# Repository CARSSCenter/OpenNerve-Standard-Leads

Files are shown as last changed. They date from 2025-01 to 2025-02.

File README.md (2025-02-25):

# OpenNerve-Standard-Leads
Leads for OpenNerve that can be manufactured under GMP using standard manufacturing processes

# About
This repository holds the design files, testing protocols, and benchtop testing results for a library of "standard" leads meant to interface with the OpenNerve IPG. Leads can be manufactured by Med-Ally LLC under GMP / design controls.

## VNS cuff electrode
This lead is designed to interface with the cervical vagus nerve or other peripheral nerves with diameters between 1 and 3.5 mm. It contains two radial platinum-iridium electrodes 1mm wide with 6mm spacing, embedded in a silicone cuff.


## SNS linear electrode
The linear electrode array is designed for sacral nerve stimulation or other peripheral stimulation. It contains four platinum-iridium electrodes 3mm wide, with a 3mm spacing, as well as anchor features for maintaining position in vivo.


## EMG needle electrode
The EMG lead contains a platinum-iridium needle electrode and suture needle. Two EMG electrodes can be attached using the interconnect for bipolar recording.

## ECG electrode
The ECG sensing lead contains two electrodes that are 3mm long, with 80mm spacing between them. It is based on the Boston Scientific 3400 S-ICD lead.

## AMS Motion Sensing Lead
The Accelerometer-based Motion Sensing (AMS) lead contains an [MIS2DH](https://www.st.com/en/mems-and-sensors/mis2dh.html) accelerometer encapsulated in silicone, which can communicate with the OpenNerve IPG via I2C.

# Disclaimer
The contents of this repository are subject to revision. No representation or warranty, express or implied, is provided in relation to the accuracy, correctness, completeness, or reliability of the information, opinions, or conclusions expressed in this repository.

The contents of this repository (the “Materials”) are experimental in nature and should be used with prudence and appropriate caution. Any use is voluntary and at your own risk.

The Materials are made available “as is” by USC (the University of Southern California and its trustees, directors, officers, employees, faculty, students, agents, affiliated organizations and their insurance carriers, if any), its collaborators Med-Ally LLC and Medipace Inc., and any other contributors to this repository (collectively, “Providers”). Providers expressly disclaim all warranties, express or implied, arising in connection with the Materials, or arising out of a course of performance, dealing, or trade usage, including, without limitation, any warranties of title, noninfringement, merchantability, or fitness for a particular purpose.

Any user of the Materials agrees to forever indemnify, defend, and hold harmless Providers from and against, and to waive any and all claims against Providers for any and all claims, suits, demands, liability, loss or damage whatsoever, including attorneys' fees, whether direct or consequential, on account of any loss, injury, death or damage to any person or (including without limitation all agents and employees of Providers and all property owned by, leased to or used by either Providers) or on account of any loss or damages to business or reputations or privacy of any persons, arising in whole or in part in any way from use of the Materials or in any way connected therewith or in any way related thereto.

The Materials, any related materials, and all intellectual property therein, are owned by Providers.

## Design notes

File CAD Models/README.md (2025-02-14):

All CAD files here were generated using SolidWorks.

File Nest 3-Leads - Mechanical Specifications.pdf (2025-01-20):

### Nest 3 – Leads

Mechanical Specifications

Page 1 of 9

### 1.0 Purpose

The purpose of this document is to provide product specifications for applicable Hornet Lead Package

### 2.0 Scope

In scope for this document are the product specifications inclusive to the Hornet IPG and charger; as part of the CARSS program Nest 3. The CARSS program stands for Center for Autonomic Nerve Recording and Stimulation Systems. The CARSS is part of the NIH Human Open Research Neural Engineering Technologies (HORNET) initiative for open-architecture, open-source implantable neuromodulation system. This includes a collaborative team between University of Southern California (USC, Los Angeles, CA), Medipace Inc (Pasedena, CA), and Med-Ally, LLC (Goose Creek, SC). The purpose of the system which the IPG and charger is a portion of is to enable community-supported neurotechnology platform to remove technical and financial hurdles to getting access to implantable neuromodulation technologies. Nest 3 focuses on a set of 5 standard leads: SNS, PDMS cuff, ECG, EMG, and AMS lead.

### 3.0 Definitions

Abbreviation | Definition
BLE | Bluetooth Low Energy. Operates on frequencies: 2.400 GHz – 2.4835 GHz
Controller | A computing device capable of running the NBS-EPG and IPG Controller application(s) tailored for physicians, the patient, or researchers.
IPG | Implantable Pulse Generator
HW | Hardware
SW | Software
PCB | Printed Circuit Board
PSD | Product Specifications Document
GUI | Graphical User Interface

Lead Mechanical Specifications
Page 2 of 9

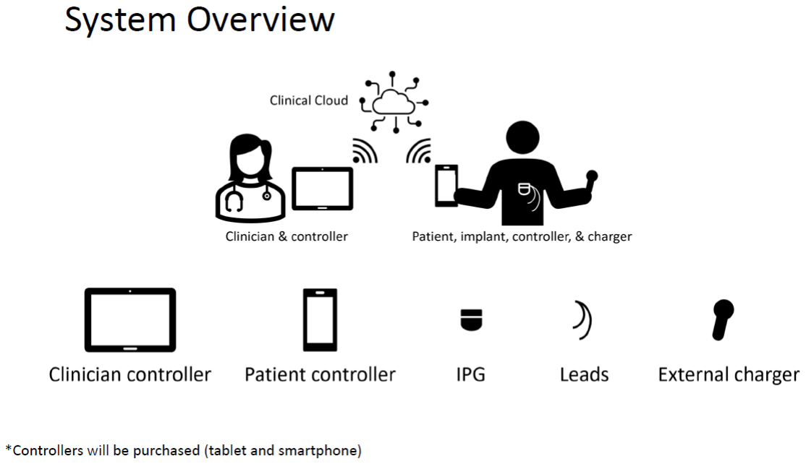
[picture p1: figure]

CONFIDENTIAL
All information contained in this document is confidential and is the sole property of Med-Ally Inc. Any reproduction in part or whole without the written permission of Med-Ally Inc. is prohibited.
Abbreviation | Definition
HIPAA | Health Insurance Portability and Accountability Act of 1996. U.S. legislation that provides data privacy and security for safeguarding medical information.
Wi-Fi | A facility allowing an electronic device to wirelessly transfer data or connect to the Internet using IEEE 802.11 standards. Operates on frequencies: 900 MHz, 2.4 GHz, 4.9 GHz, 5 GHz, 5.9 GHz and 60 GHz.
NIH | National Institute for Health
CARRS | Center for Autonomic Nerve Recording and Stimulation Systems
Hornet | Human Open Research Neural Engineering Technologies
Nest | Major component or module of the CARRS system

### 4.0 General Description of Product

The CARRS system is an open source system to enable developments in stimulation and sensing technologies. The system is capable of closed loop stimulation and sensing or can be used independently. The system components are: external charger and controller, implantable pulse generator, collection of interoperable and implantable leads.

Each portion of the CARSS system has been split into major components called nests. See

Page 3 of 9

figure below for details of major components or modules of the CARRS system:

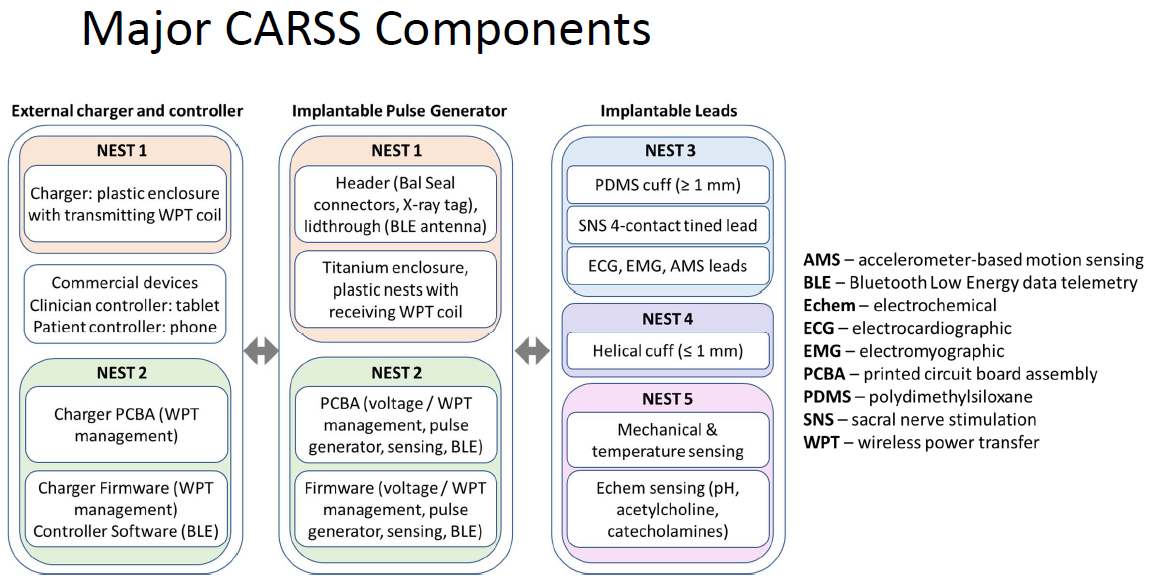
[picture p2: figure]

This document will only address Nest 1.
The IPG and charger for the CARRS system will be designed with the following engineering design principles as applicable:
- Material and component selection for maximizing the performance.
- Long-term reliability, redundancy, and fail-safe operations.
- Modularity, plug-and-play operation and off-the-shelf components.
- Preference for simpler and proven solutions over more complex and higher-risk ones.

### 6.0 Specifications

6.1 Leads Mechanical Specifications
PRD ID | Category | Specification Text
PRD-LDS-0001 | All | The leads are provided in the following lengths: 35 cm

Page 4 of 9

PRD ID | Category | Specification Text
| | 50 cm 50 cm 70 cm
PRD-LDS-0002 | All | The outside diameter of the leads shall be 1.27 mm diameter
PRD-LDS-0003 | All | The SNS, PDMS cuff, EMG, ECG, and AMS lead have 2 or 4 filar coiled leads with 0.70 mm pitch or greater.
PRD-LDS-0004 | All | The SNS, PDMS cuff, EMG, ECG, interconnect and AMS lead wire diameter is .102 mm/ 0.004” with 0.0127 mm/0.0005” thick coating.
PRD-LDS-0005 | All | The proximal contacts have 1.5mm length contacts.
PRD-LDS-0006 | All | The proximal set screw contact is 3mm in length.
PRD-LDS-0007 | All | Tines and trumpet anchor for anchoring can be added for each lead as needed.
PRD-LDS-0008 | All | The each connector utilizes a mechanism that holds the inserted lead in place. (e.g. set screw)
PRD-LDS-0009 | All | All the materials of the Lead Kit that are in contact with the body have been selected as known biocompatible.
PRD-LDS-0010 | All | The primary components for the Leads and interconnects shall be fabricated from the following materials: • Lead Body: Polyurethane, Pellethane 2363-55D • Proximal Inner Tube: PEEK • Distal Inner Tube: Polyurethane, Pellethane 2363-80A • Distal Electrodes: Platinum-Iridium (90/10) • Proximal Contacts: MP35N • Conductor Cable: PTFE coated Platinum-Iridium (80/20) • Setscrew: Titanium • Connector Block: MP35N

Page 5 of 9

PRD ID | Category | Specification Text
| | • Bal Seal connectors: MP35N and Pt-Ir • Silicone molded components Silicone Rubber -Med-4850, or similar • Connector block and set screw: 316L stainless steel • Misc Adhesives: Epoxy - Epotek 301, Silicone Rubber - Med-2000, urethane adhesive, silicone adhesive MED3-4213 • Suture: polypropylene or silk • Tines: pellethane • Suture Needle, crimp tubes: 316L Stainless Steel
PRD-SNS-0001 | SNS | SNS leads have electrodes on the distal end that are 3 mm in length with 3 mm space between electrodes
PRD-SNS-0002 | SNS | Up to 4 tines in series are added to the lead body to aid in lead retention and stability in vivo.
PRD-SNS-0003 | SNS | The lead systems incorporates a radio-opaque marker at the distal array in the form of platinum electrodes
PRD-SNS-0004 | SNS | The leads with a stylet inserted is able to pass completely through an 18-gauge needle
PRD-INT-0001 | Interconnect | The distal connector of the interconnect incorporates a connector block and set screw for securing the lead to the connector
PRD-INT-0002 | Interconnect | The distal connector of the interconnect accommodates two bipolar male connectors.
PRD-INT-0003 | Interconnect | The proximal connector of the interconnect interfaces with a quadipolar Sygnus Neuro Bal Seal connector in the IPG header.
PRD-INT-0004 | Interconnect | The interconnect connection portion is smaller than 0.5” X 1.5” X 0.5”
PRD-EMG-0001 | EMG | The EMG lead incorporates a Suture style needle

Page 6 of 9

PRD ID | Category | Specification Text
PRD-EMG-0002 | EMG | The EMG lead incorporates a suture connecting the needle to the stimulating portions of the lead
PRD-EMG-0003 | EMG | The EMG lead contains a single stimulating or sensing electrode
PRD-EMG-0004 | EMG | The EMG lead contains a Tumpet anchor to anchor electrode in place
PRD-EMG-0005 | EMG | The EMG lead interfaces with the bipolar connection.
PRD-EMG-0006 | EMG | The insertion needle length on the EMG lead is 32 mm
PRD-ECG-0001 | ECG | The ECG lead has two electrodes that can be 3mm to 100 mm apart.
PRD-ECG-0002 | ECG | The ECG lead has two anchor points: one at the end of the lead and the second proximal to the first electrode
PRD-ECG-0003 | ECG | The ECG lead interfaces with the bipolar connection
PRD-CUF-0001 | Cuff | The cuff electrode will have an inner diameter that accommodates nerves 2.5-5.5 mm in diameter – nominally 3.58 mm nerve.
PRD-CUF-0002 | Cuff | Cuff leads shall have two electrodes for bipolar stimulation.
PRD-CUF-0003 | Cuff | Cuff length along the nerve is 10 mm
PRD-CUF-0004 | Cuff | Lead exits cuff parallel to nerve
PRD-CUF-0005 | Cuff | Cuff electrode spacing is 2.5mm
PRD-CUF-0006 | Cuff | Electrodes are located 2.25mm inboard from edge of cuff
PRD-CUF-0007 | Cuff | Silicone cuff thickness is 1 mm
PRD-CUF-0008 | Cuff | Cuff includes dual sutures 35 mm long and 0.2mm diameter

Page 7 of 9

6.2 Testing Requirements
PRD ID | Specification Text
PRD-LDS-0011 | The leads contacts are electrically isolated to prevent interference between signals.
PRD-LDS-0012 | The Leads and Extensions shall be designed to withstand the following flexure cycles: -The Lead and Extension Connector shall withstand a minimum of 82,000 flex cycles. -The Lead and Extension body sections shall withstand a minimum of 47,000 flex cycles. Reference: EN45502-2-1 CENELEC Standard for Brady Pacemakers Testing will be performed per EN4552-2-1/ISO14708-2: 23.5.
PRD-LDS-0013 | Once the lead is locked in place into the IPG port or extension with the set screw fully torqued, the retention force of the lead shall be 10 N minimum along the lead axis relative to the connector. This retention force may exceed the destructive pull force of the inserted lead. EN45501-1 section 23.6 / ISO 14708-2: 23.6
PRD-LDS-0014 | When a tensile force of 5N is applied for 2 seconds along the main axis the of the lead or extension the assembly must not electrically and/or mechanically fail. ISO 14708-2: 23.3
PRD-LDS-0015 | Lead Insertion/Withdrawal Force Connector: The insertion and withdrawal force of a lead connector array into the IPG port connector or lead Extension port shall not exceed 2.2 lbs (9.8 N).
PRD ID | Category | Specification Text
PRD-AMS-0001 | AMS | The AMS lead is a quadripolar lead
PRD-AMS-0002 | AMS | The AMS lead has three suture points to anchor AMS distal end

Page 8 of 9

PRD ID | Specification Text
PRD-LDS-0016 | The interface between the extension distal connector body and a connected component shall not electrically and/or mechanically fail when tensile force of 2.2 lbf (9.8N) is applied between the components or across theirinterface. Deformation of componentsis allowable. Fracture of tubing orseparation of tubing from a component is not allowable. Examples of tensile force arrangements between an attached component and the Extension body.
PRD-LDS-0017 | The resistance for each connection in the distal connector shall remain ≤1000 Ohms and must not mechanically fail when bent 45°±2° off the main axis in any direction ISO 14708-2: 6.2.3
PRD-LDS-0018 | All the leads in the Leads Kit shall observe industry standard wiring practices for this type of application. The contact female connectors at the distal end and male contacts at the proximal end shall be connected through a one-to-one connection.
PRD-LDS-0019 | The proximal contact arrays of the Lead shall withstand 20 insertion and withdrawal cycles into the connector on the interconnect cable without causing physical or functional damage to the Lead.
PRD-LDS-0020 | The proximal contact arrays of the Lead and Extension shall withstand 20 insertion and withdrawal cycles into the port connector on the IPG without causing physical or functional damage to the Lead.
PRD-LDS-0021 | The lead assemblies should be able to withstand (function after experiencing) the following:

Page 9 of 9

PRD ID | Specification Text
| Accelerated aging per ISO 14708-1:19-1
PRD-LDS-0022 | When the lead or Extension assembly is dry in air, the electrical leakage between conductors at 100 ± 5 Volts DC shall be ≤10 microamperes. ISO 14708-2: 16.1
PRD-LDS-0023 | When the lead or Extension assembly is dry in air, the electrical leakage from any conductor to the outside lead body at 1000 ± 50 Volts DC shall be ≤0.75 microamperes per mm². ISO 14708-2: 16.2

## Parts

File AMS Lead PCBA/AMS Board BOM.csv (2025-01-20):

Name | Description | Designator | Manufacturer 1 | Manufacturer Part Number 1
ZRB15XR61A106ME01D | Capacitor, 10uf, X5R, 10V, 20%, 0402, Implant-grade | C200 | Murata | ZRB15XR61A106ME01D
GCM155R71C104KA55 | Capacitor, 0.1uF, X7R, 16V, 10%, 0402, Implant-grade | C201 | Murata | GCM155R71C104KA55J
MIS2DHTR | Analog Circuit, Accelerometer, LGA-12 | U200 | STMicroelectronics | MIS2DHTR

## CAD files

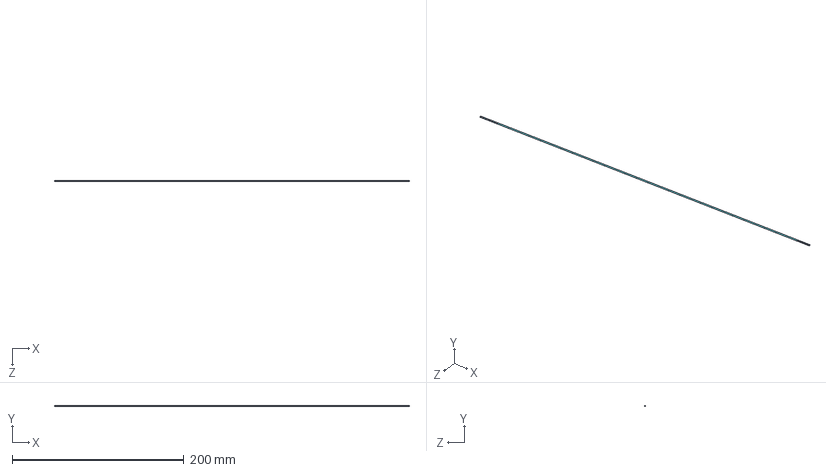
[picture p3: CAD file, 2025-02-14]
CAD Models/8247, 4 X 4 Lead Assembly with Tines, Rev. 2.1.STEP
413.5 x 1.27 x 1.27 mm
8177 Contact, Proximal,1.50 MM. Rev 1.0 x 4
8181 Pellethane 55D Tube, 1.245 MM, Rev. 1.0 x 4
8184, Proximal Lead Tip, Rev. 1.0
8263 Peak Single Lumen Tube Rev 2.0
8146 Proximal Contact - 3 mm Rev 1.0
8145 Electrode - 3 mm Rev 1.0 x 4
8179, Pellethane Tube 55D. 3.00MM, Rev. 1.0 x 3
8147 Distal Tip Rev 2.0
8204, Pellethane Tube 55D, 374 mm, Rev. 1.0
8178, Pellethane Tube 55D, 0.87MM, Rev. 1.0

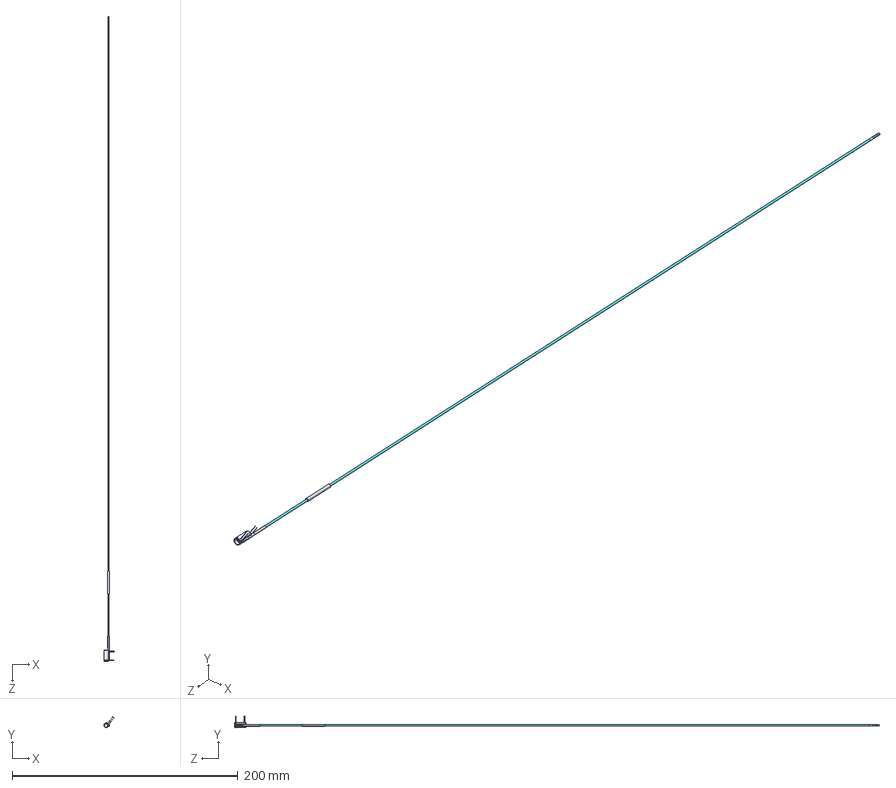
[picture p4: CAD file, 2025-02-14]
CAD Models/8289, Bipolar Cuff, Rev 1.1.STEP
9.17 x 10.2 x 571.5 mm
3mm I.D. Cuff
3mm Electrode x 2
3mm Suture Cord no furl x 2
3mm I.D. Cuff transition
8158 Proximal Contact-3 mm Rev 2.0
8184, Proximal Lead Tip, Rev. 1.1
Inner Connect XXXX, Outer Tubing 80A 550 mm, Rev 1.0
XXXX, Outer Tubing 80A, 1.245mm, Rev 1.0 x 2
8159 Proximal Contact-1.5 mm Rev 2.0 x 2
8263, PEEK Single Lumen Tube, Rev 1.1
8XXX, Silicone Tube, Rev 0.1

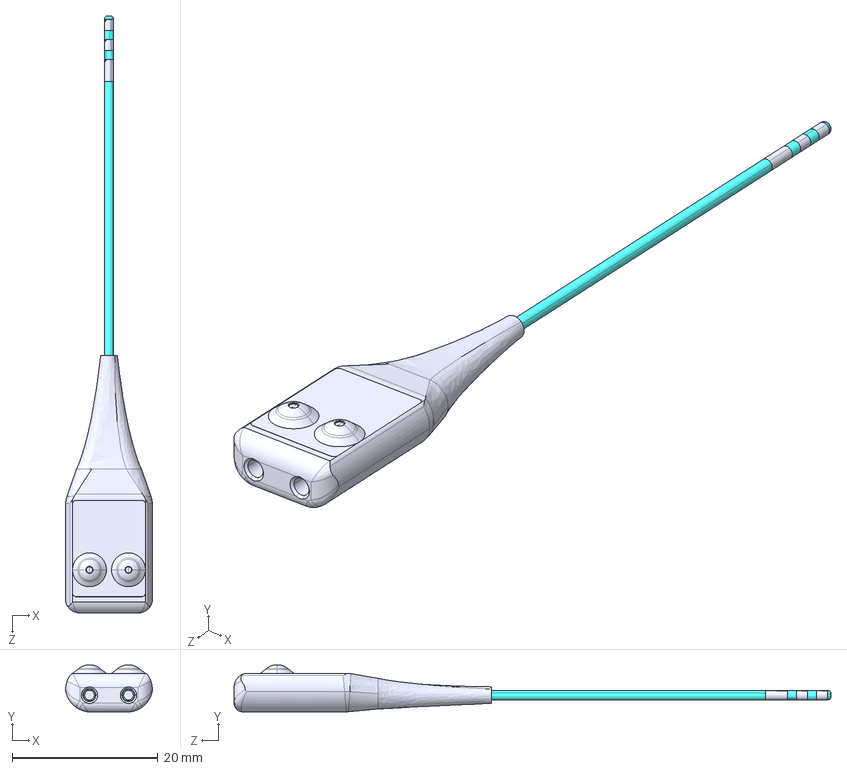
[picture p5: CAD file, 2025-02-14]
CAD Models/8340, Lead Extension, Rev 1.2.STEP
11.9 x 6.43 x 81.9 mm
septum top cover
8XXX, 2X2 Interconnect - Main, Rev 0.3
MAN_ExtenderConnectorBlock x 2
MAN_BalCon_27Mar2019 x 2
MAN_BalSeal x 6
8158 Proximal Contact-3 mm Rev 1.0
8184, Proximal Lead Tip, Rev. 1.0
Inner Connect XXXX, Outer Tubing 80A 60 mm, Rev 1.0
XXXX, Outer Tubing 80A, 1.245mm, Rev 1.0 x 2
8159 Proximal Contact-1.5 mm Rev 1.0 x 2
NK SCR 001 #2-56 X .062 LONG CUP POINT SETSCREW REV. 3.0_NT10015-000_A x 2
8263 Peak Single Lumen Tube Rev 1.0

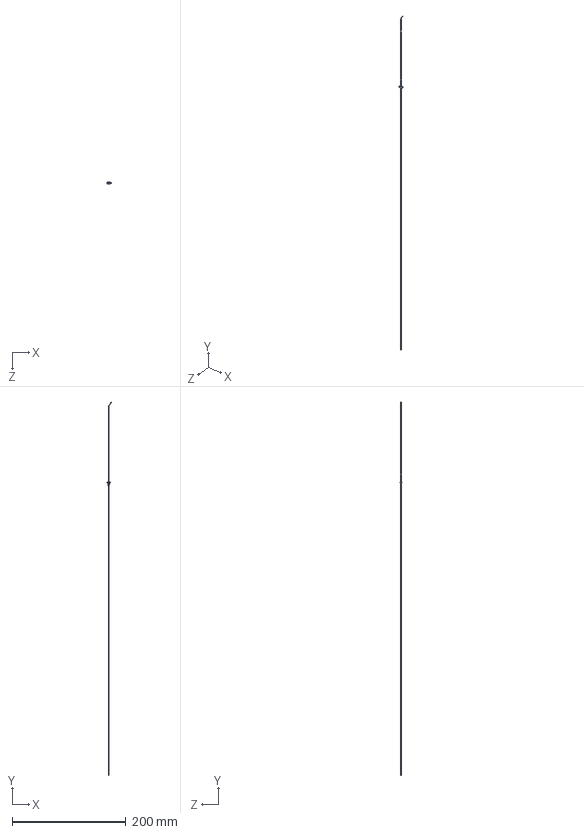
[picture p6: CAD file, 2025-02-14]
CAD Models/8291, EMG Lead, Rev 1.1.STEP
7.88 x 655.0 x 4.00 mm
8307, 1 Filar Coil, Rev 0.1 x 2
ECG XXXX, Outer Tubing 80A 60 mm, Rev 1.1
8292, EMG Suture-Needle, Rev 1.0
8294, Polypropylene Filament, Rev 1.0
8263, PEEK Single Lumen Tube, Rev 1.1
8158 Proximal Contact-3 mm Rev 1.0
8177 Contact, Proximal,1.50 MM. Rev 1.0
8XXX Electrode - 15 mm Rev 0.1
8309, Trumpet Anchor, Rev 1.0
8XXX, Distal Lead Tip, Rev. 0.1
8184, Proximal Lead Tip, Rev. 1.1
8181 Pellethane 55D Tube, 1.245 MM, Rev. 1.0

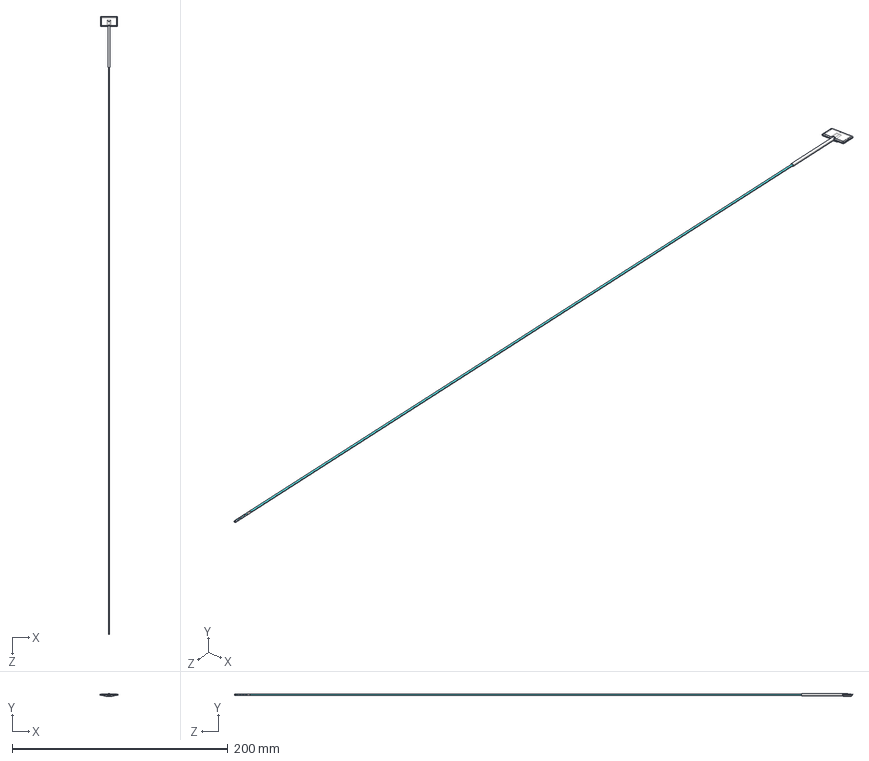
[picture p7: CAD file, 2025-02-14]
CAD Models/8303, AMS Lead, Rev 1.1.STEP
16.0 x 3.12 x 572.5 mm
8XXX, 4 80Pt20Ir Wire
Inner Connect XXXX, Outer Tubing 80A 550 mm, Rev 1.0
8263, PEEK Single Lumen Tube, Rev 2.1
8262, Silicone Tubing 1.25 mm ID x 1.5 in, Rev 0.1
8159 Proximal Contact-1.5 mm Rev 1.0 x 4
8158 Proximal Contact-3 mm Rev 1.0
pinShape x 16
8XXX, Silicone Dip, Rev 0.1
8181 Pellethane 55D Tube, 1.245 MM, Rev. 1.0 x 4
8184, Proximal Lead Tip, Rev. 1.1

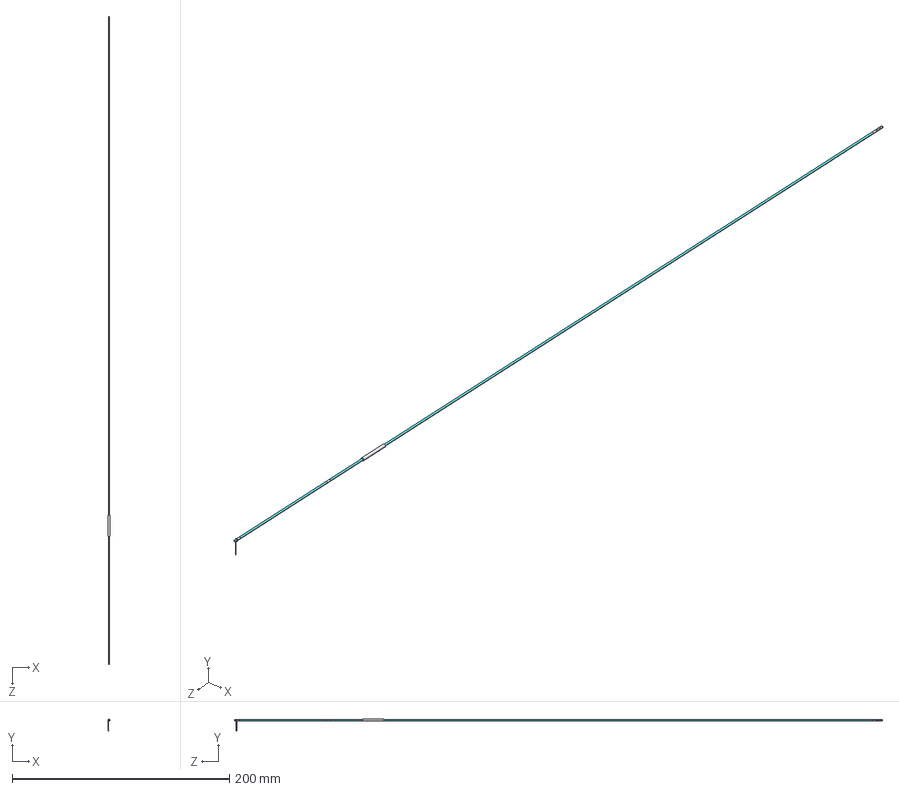
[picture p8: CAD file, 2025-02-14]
CAD Models/8290, ECG Lead, Rev. 1.1.STEP
2.00 x 11.0 x 596.7 mm
ECG XXXX, Outer Tubing 80A 60 mm, Rev 1.0
8262, Silicone Tubing 1.25 mm ID x 2 cm, Rev 0.1
8158 Proximal Contact-3 mm Rev 1.0
8389, Electrode, Rev 1.1 x 2
8159 Proximal Contact-1.5 mm Rev 1.0 x 2
8XXX, 1.27mm Suture Cord no furl, Rev 0.1
8263, PEEK Single Lumen Tube, Rev 1.1
8XXX, Distal Lead Tip, Rev. 0.1
8181 Pellethane 55D Tube, 1.245 MM, Rev. 1.0 x 2
ECG XXXX, Outer Tubing 80A 8 mm, Rev 1.0
XXXX, Outer Tubing 80A, 1.245mm, Rev 1.0
8184, Proximal Lead Tip, Rev. 1.1

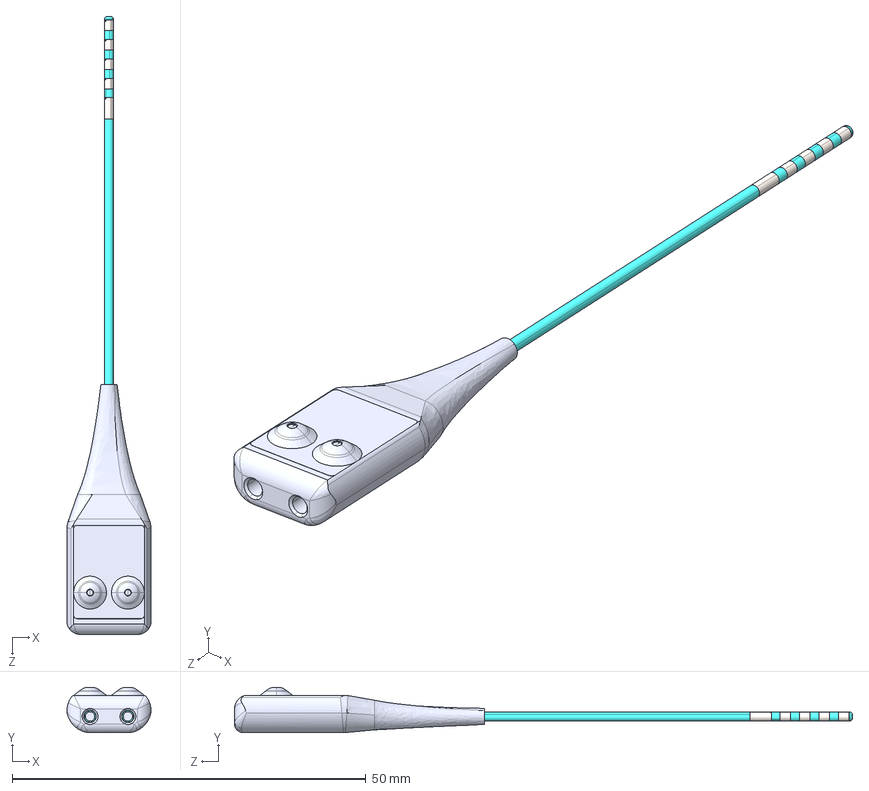
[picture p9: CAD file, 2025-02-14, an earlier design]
CAD Models/8340, Lead Extension, Rev 1.1.STEP
11.9 x 6.43 x 87.4 mm
septum top cover
8XXX, 2X2 Interconnect - Main, Rev 0.3
MAN_ExtenderConnectorBlock x 2
MAN_BalCon_27Mar2019 x 4
MAN_BalSeal x 8
8158 Proximal Contact-3 mm Rev 1.0
8184, Proximal Lead Tip, Rev. 1.0
Inner Connect XXXX, Outer Tubing 80A 60 mm, Rev 1.0
XXXX, Outer Tubing 80A, 1.245mm, Rev 1.0 x 4
8159 Proximal Contact-1.5 mm Rev 1.0 x 4
NK SCR 001 #2-56 X .062 LONG CUP POINT SETSCREW REV. 3.0_NT10015-000_A x 2
8263 Peak Single Lumen Tube Rev 1.0

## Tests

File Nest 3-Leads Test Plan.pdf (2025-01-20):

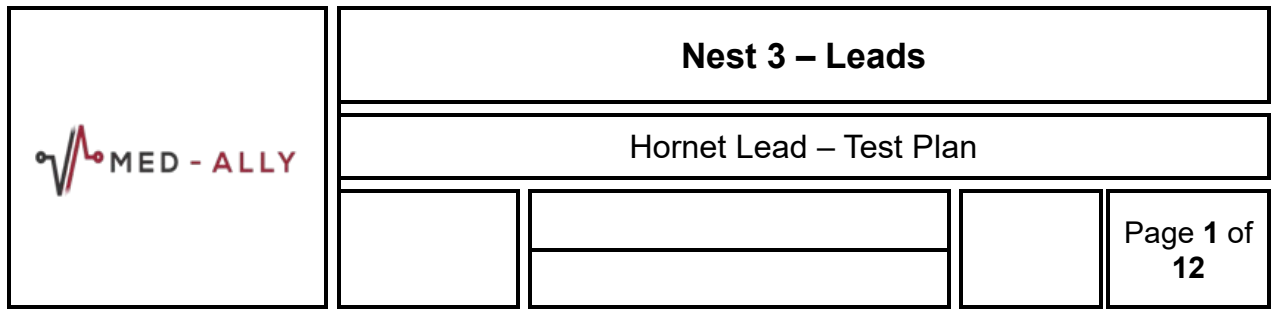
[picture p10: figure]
Nest 3 – Leads; Hornet Lead – Test Plan; Page 1 of 12

### 1. Purpose

The purpose of this document is to summarize how The Hornet Leads will be tested to show that the design, construction and functionality of the device meets design and functionality requirements and complies with applicable standards.

### 2. Scope

This document is valid for the Hornet Leads. The test plan outlined in this document is progressive and may be released at various stages prior to finalization. This document includes an overview of applicable testing requirements, equipment, and documentation.

### 3. References

Document No. | Title
ISO 14708-1 & 3 | Implants for surgery – Active Implantable Medical Devices
| ISO 11607-1:2006 and ASTM F1980-07(2011)
BS EN 45502-2-1:2003 | Active Implantable Medical Devices Part 2-1: Particular requirements for active im-plantable medical devices intended to treat bradyarrhythmia (cardiac pacemakers)

### 4. Definitions

Abbreviation or Term | Definition
DVT | Design Verification Test
Engineering Bench Level Test | Also known as Engineering Design Verification. Prototype samples are created and subjected to internal and external testing to verify that design requirements and specifications are being met. The results from these tests will determine if the product gets released to Production.
IPG | Implantable Pulse Generator

### 5. General Description of Product

The CARRS system is an open source system to enable developments in stimulation and sensing technologies. The system is capable of closed loop stimulation and sensing or can be used independently. The system components are: external charger and controller, implantable pulse generator, collection of interoperable and implantable leads. This document is focused on leads only.

### Hornet Lead – Test Plan

### Page 2 of 12

CONFIDENTIAL
All information contained in this document is confidential and is the sole property of Med-Ally Inc. Any reproduction in part or whole without the written permission of Med-Ally Inc. is prohibited

### 6. Methods

Each test will be summarized via an approved quality management system controlled protocol. The test will be conducted per the protocol with records and deviations recorded. Results and conclusions along with any needed discussion and recommendations will be documented in a report. The test results will be compiled and summarized in a Test Report or appendix.

### 7. Sample Size Strategy

Three to nine samples for each test will be used. This number is to show the ability of the lead to meet the shown criteria. For formal DVT testing for human use these values will need to be reviewed per use case based on risk and application to evaluate if test and sample size can be utilized or if the test needs to be supplemented or repeated. Planned testing units are represented below for each test.

### 8. DVT Test Details 8.1. Tests that require pre-conditioning

8.1.1. Baseline functional lead measurements shall be recorded and cataloged.
8.1.2. Ensure measurements for each lead it clearly identifiable.
8.1.3. Preconditioning protocol:
8.1.3.1 Pre-conditioning bath of 9 g/l saline at 37 deg C +/- 5 deg C submerged for 10 days. 8.1.3.2 Immediately prior to testing the lead shall be rinsed in distilled or deionized water, and then wiped free of surface water.
Test | Testing Details
Lead Body Pull Test at 5 N | Purpose | ►Leads shall withstand the tensile forces that might occur after implantation, without fracture of any conductors or joints or breaching of any functional electrical isolation.
| Standards | ►ISO 14708-2:23.3
| Acceptance Criteria | ► Leads exhibits no permanent elongation in exceeds of 5% nor any permanent functional damage; ►The continuity measurements do not change from baseline to after conditioning; ►The leakage current measured between each conductor and the reference electrode and between any two conductors that have an exposed conductive surface intended for contact with tissue is <= 2 mA during the voltage application.
| Equipment | ►preconditioning bath of approximately 9 g/l saline at 37 deg C +/- 5 °C, ►a tensile load tester,

### Hornet Lead – Test Plan

### Page 3 of 12

CONFIDENTIAL
All information contained in this document is confidential and is the sole property of Med-Ally Inc. Any reproduction in part or whole without the
Test | Testing Details
| | ►a resistance meter, ►a reference electrode plate having a noble metal surface with a minimum area of 500 mm2 that can be located in the test bath (same as precondition-ing bath requirements) ►a leakage current tester, capable of applying 100 V and supplying a current of at least 2 mA.
| Lead Samples | ►20 cm SNS leads will be utilized. ►SNS lead was chosen because the quadripolar leads represent the worst case of lead body stresses with 4 filar vs. 2 filar. ►Qty 9 as representative samples will be used.

Test Set Up

►After conditioning:
►The LEAD shall be fitted in the tensile tester, clamped at the metallic surface of the LEAD connector pin and at the appropriate point on the distal end of the LEAD. The distance between the lamping points shall be measured.
- The lead shall be subjected to a tensile load, limited to a value causing 20% elongation, otherwise increased to at least 5N. The tensile load shall be sustained for at least 1 min, then relieved.
►The tensile load application shall be repeated for each combination of distal end tip and lead connector pin. This may be accomplished by using multiple leads as the test sample.
►The electrical continuity of each conduction path shall be verified by measuring DC resistance
►The insulation integrity of each lead shall be verified by immersing the outer covering, other than 20 mm of any exposed conductive surface, in the test bath. The test specimen(s) shall be placed in the test bath within 30 min of removal from the preconditioning bath and shall be immersed in the test bath for a minimum of 1 h before proceeding. The test specimen shall be positioned in the test bath so that the lead body is not less than 50 mm nor more than 200 mm from the reference electrode plate.
►The insulation shall then be subjected to a 100 V +/- V DC test potential between each conductor and the reference electrode and between any two conductors that have an exposed conductive surface intended for contact with tissue. The test voltage shall attain the full value within 0,1 s to 5 s. The test potential shall be maintained at full value for at least 15 s before being lowered to zero.
Report ► Generate Report

### Hornet Lead – Test Plan

### Page 4 of 12

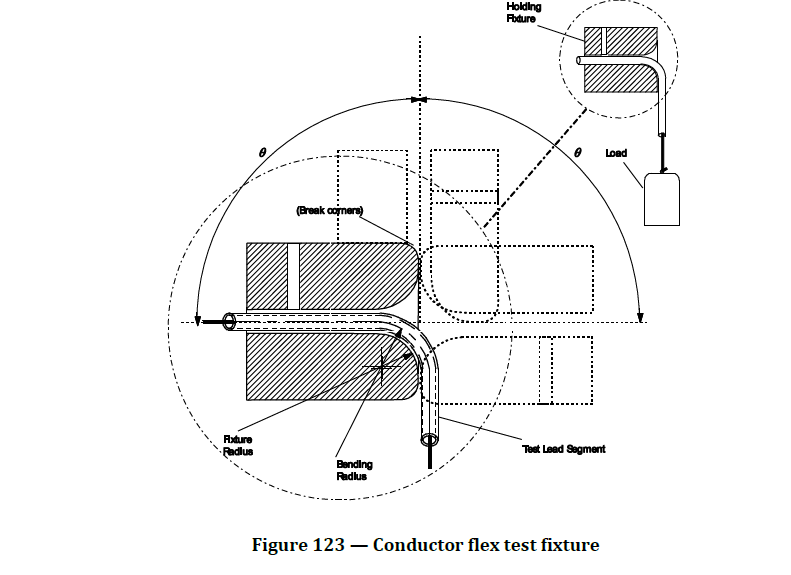
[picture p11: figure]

CONFIDENTIAL
All information contained in this document is confidential and is the sole property of Med-Ally Inc. Any reproduction in part or whole without the
Test | Testing Details
| Purpose | ►Implantable leads shall withstand the flexural stresses that might occur after implantation, without fracture of any conductor. ►Test 1 to be conducted to be conducted 5 cm from the connecting features of stimulation or sensing on the distal end on lead body. ►Test 2 to be conducted on each type of uniform lead body on the proximal end construction for each lead type.
| Standards | ►ISO14708-2:23.5
| Acceptance Criteria | ► Measured resistance and conductance has not significantly varied from baseline values.

Lead Flexure
Cycling Test

Equipment

►a resistance meter,
►functional test equipment ►Figure 123 Test fixture:

►Figure 124 Test Fixtures

### Hornet Lead – Test Plan

### Page 5 of 12

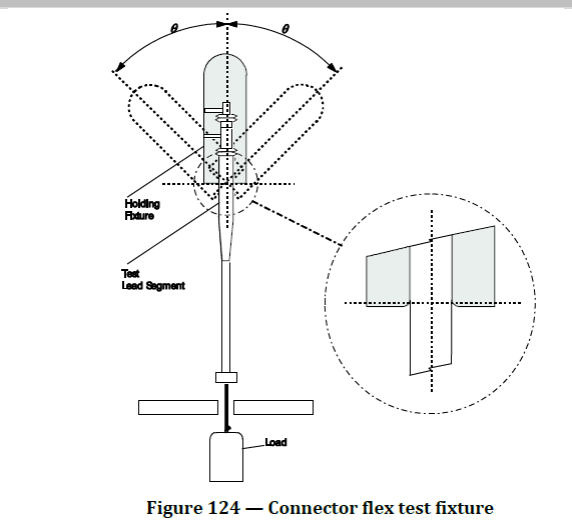
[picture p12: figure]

CONFIDENTIAL
All information contained in this document is confidential and is the sole property of Med-Ally Inc. Any reproduction in part or whole without the
Test | Testing Details

Lead Samples

►20 cm leads will be utilized.
►Qty 3 SNS leads as representative samples will be used of a quadripolar lead body and Qty 3 Cuff/VNS lead samples will be used of a bipolar lead body sample.
►A mix of SNS (4 filar) and VNS leads (2 filar) will be utilized to compare representative samples for both lead configurations. The test plan can be used across different lead applications due to the test purpose as outlined above.

Test Set Up

►Perform preconditioning
Test 1: Flexible lead segments – 5 cm from distal end
►Using special holding fixture (see figure 123 from standard). The inside bore of the fixture shall be no greater than 110% of the diameter of the lead segment under test. At the lower end of the fixture, the inside surface shall be formed into a bell mouth having a radius such that, when the test segment conforms to the contour of the fixture, the center line of the test segment forms a 6 mm +/- 0.1 mm center line bending radius
►The fixture shall be mounted in a machine that can oscillate the fixture 90 +0/-5 degrees from the vertical and forces the test segment to flex in the bell mouth of the fixture. The lead test segment shall be mounted to hang vertically under gravity in the holding fixture, oriented in the worst-case test condition when the test segment allows multiple orientations. A load sufficient to ensure that the center line of the test segment conforms to the bending radius shall be attached to the lower end of a thin, flexible line (cord) strung through the test segment. For LEAD bodies with no accessible

### Hornet Lead – Test Plan

### Page 6 of 12

CONFIDENTIAL
All information contained in this document is confidential and is the sole property of Med-Ally Inc. Any reproduction in part or whole without the
Test | Testing Details lumen, a minimal tensile load may be applied directly to the test segment, so that it conforms to the bending radius. ►The fixture shall be oscillated through an angle 90 degrees +0/-5 deg each side of vertical at a rate of approximately 2 Hz for a minimum of 47,000 cycles. (minimize vibration). ►The test shall be repeated for each unique uniform flexible part of the lead body. ►Post flexure measure resistance and functional conductivity Test 2: Lead proximal connector joints between lead and connector body – proximal end ► Using special holding fixture (see figure 124 from standard) (similar in form to header). The holding fixture shall be made of rigid materials with representative corners and materials to header. ►The holding fixture shall be mounted in a machine that can rotate the fixture 45 deg +/- 2 deg from the vertical (figure 124 from standard). The center of rotation shall be in the plane where the rounded corners of the holding fixture begin. The holding fixture shall allow the lead connector an attached lead segment to hang vertically under gravity. The lead connector shall be fitted into the holding fixture, oriented in the worst-case test condition and retained by the set screw mechanism. ►A load shall be attached to the lead segment 10 cm +/- 0.5 cm from the center of rotation of the holding fixture. The load attachment mechanism shall ensure that there is no relative motion between the conductor and the tubing at the point of attachment. The load shall be 100 g +/- 5 g (including the attachment mechanism). ►The holding fixture shall then be oscillated 45 deg +/- 2 degrees each side of vertical at a rate of approximately 2 Hz for a minimum of 82,000 cycles. ►The test shall be repeated for each joint in the lead body. ►Post flexure measure resistance and functional conductivity
Report | ►Generate Report
Qualification Test | Testing Details
Lead Connector | Purpose | ► Demonstrate the retention force provided by the implantable connector shall be greater than or equal to 10 N. For the lead to header and lead to

### Hornet Lead – Test Plan

### Page 7 of 12

CONFIDENTIAL
All information contained in this document is confidential and is the sole property of Med-Ally Inc. Any reproduction in part or whole without the
Qualification Test | Testing Details
Pull Test at 10 N | interconnect.
Standards | ►ISO 14708-2: 23.6
Acceptance Criteria | ►The lead shall not be disconnected at value of 10 N or less.
Equipment | ► The insertion and removal force will be measured by the Instron S/N 3367Q1264. ► Saline bath, approximately 9 g/l at 37oC ± 5oC
Lead Samples | ►20 cm leads will be utilized. ►Qty 3 SNS leads as representative samples will be used of a quadripolar lead body and Qty 3 Cuff/VNS lead samples will be used of a bipolar lead body sample. ►A mix of SNS (4 filar) and VNS leads (2 filar) will be utilized to compare representative samples for both lead configurations. The test plan can be used across different lead applications due to the test purpose as outlined above.
Test Set Up | ► The implantable connector pair shall be mated and immersed in a saline bath, approximately 9 g/l at 37oC ± 5oC, for a minimum of 10 days. ► Remove the lead from the saline bath. ► Subject the lead to header to straight pull of 10 N +/- 0.5 N for a minimum of 10 seconds.
Report | ►Generate report

### 8.2. Tests that DO NOT require pre-conditioning

8.2.1. Baseline functional lead measurements shall be recorded and cataloged.
8.2.2. Ensure measurements for each lead it clearly identifiable.
Qualification Test | Testing Details
Lead leakage current < 10 uA | Purpose | ► To test that the lead has effective functional electrical insulation between conductors.
| Standards | ►ISO 14708-2: 16.1 / IEC 60601-1, IEC 62353
| Acceptance Criteria | ►The leads must have no more than 100 uA current leakage when tested to a minimum of 50 V DC in normal condition (NC). ► Type BF – Electrically connected to Patient but not directly to heart

### Hornet Lead – Test Plan

### Page 8 of 12

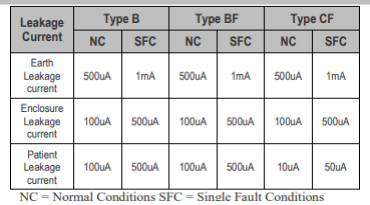
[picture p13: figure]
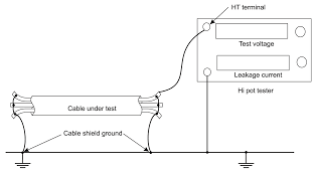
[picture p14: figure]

CONFIDENTIAL
All information contained in this document is confidential and is the sole property of Med-Ally Inc. Any reproduction in part or whole without the
Qualification Test | Testing Details
Equipment | ► Guardian Electrical Safety Analyzer model 19032 from Chroma System Solutions to measure current leakage.
Lead Samples | ►20 cm leads will be utilized. ►Qty 9 SNS leads as representative samples will be used of a quadripolar lead body as the worst case sample.
Test Set Up | ► High and low leakage current limits will be set to 1 mA. The applied voltage will be set to 50 V DC.
Report | ►Generate Report
Qualification Test | Testing Details
Lead DC Charge <= 0.75 UA/mm² | Purpose | ►To confirm the maximum current density at any electrode is no more than 0.75 uA/mm² . Except for its intended function, an IMPLANTABLE PULSE GENERATOR, when in use, shall be electrically neutral. No d.c. leakage current of more than 1 μA shall occur in any of the current pathways of the CASE TERMINALS and no more than 0.1 μA in the current pathways of any other TERMINAL.
| Standards | ►ISO 14708-2: 16.2

### Hornet Lead – Test Plan

### Page 9 of 12

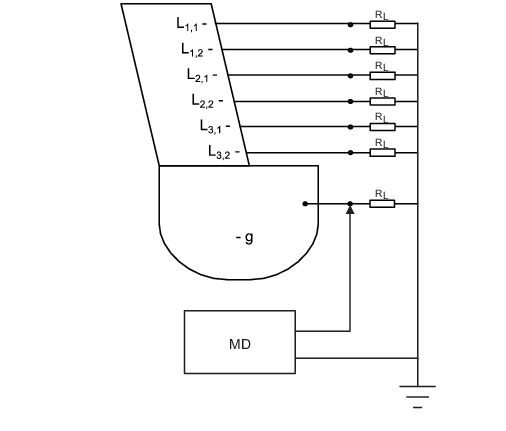
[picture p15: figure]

CONFIDENTIAL
All information contained in this document is confidential and is the sole property of Med-Ally Inc. Any reproduction in part or whole without the
Qualification Test | Testing Details
| Acceptance Criteria | ► maximum current density at any electrode is no more than 0.75 uA/mm² except for its intended function.
| Equipment | ► Guardian Electrical Safety Analyzer model 19032 from Chroma System Solutions to measure current leakage.
| Lead Samples | ►40 cm leads will be utilized. ►Qty 9 VNS leads as representative samples will be used of a cuff lead sam-ple as this is the most likely to use high frequency signals, which represents the highest risk for lead DC charge.

Test Set Up

- The IMPLANTABLE PULSE GENERATOR shall be set to the nominal settings recommended by the MANUFACTURER (i.e. the “factory recommended settings”) but with the PULSE AMPLITUDE and PULSE DURATION programmed to the highest available settings.
►Each electrically conductive part of the IMPLANTABLE PULSE GENERATOR in contact with body tissue when the device is implanted shall be identified and connected to a common bus through 500 1 % load resistors RL (see Figure 122). For devices with fewer terminals than shown in Figure 122, the associated resistors RL are not used.

Example image:

►Measure the average direct voltage across each load resistor with the measuring device. Steady-state conditions shall be reached before the measurement is made.
►The measurement of the individual terminal currents may be made with a plurality of measuring devices.

### Hornet Lead – Test Plan

### Page 10 of 12

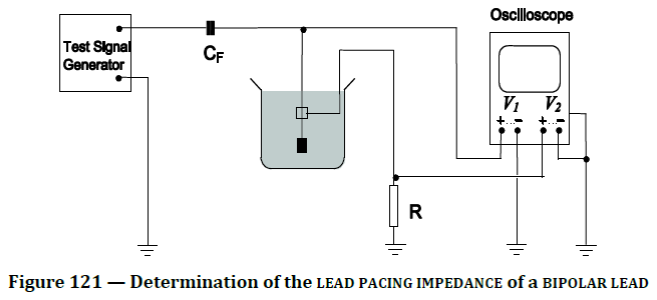
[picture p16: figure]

CONFIDENTIAL
All information contained in this document is confidential and is the sole property of Med-Ally Inc. Any reproduction in part or whole without the
Qualification Test | Testing Details
| Report | ►Generate report
Qualification Test | Testing Details
| Purpose | ►Measurement of lead stimulating impedance using in vitro approach
| Standards | ► ISO 14708-2: 6.2.3
| Acceptance Criteria | ►Resistance is acceptable. Typically < 50 ohms.
| Equipment | ►Oscilloscope ►Test Signal Generator
| Lead Samples | ►40 cm leads will be utilized. ►Qty 9 VNS leads as representative samples will be used of a cuff lead sample with the DC charge test.

Lead contact
impedance < 1000
ohm

Test Set Up

- The LEAD shall be inserted into the test body so that the ELECTRODES are at least 10 mm from any fluid boundary.
►The test signal generator shall be connected through a 33 μF +/- 5 % series film capacitor (CF) to the LEAD, the metal plates and the oscilloscope as shown in Figure 121.

►Set the signal generator to provide negative pulses, 65 +/- 5 per minute, amplitude 4 V+/-0.1 V and duration (Tp ) of 0.5 ms +/- 0.05 ms. The LEAD current shall be determined by measuring the voltage drop across the 10

### Hornet Lead – Test Plan

### Page 11 of 12

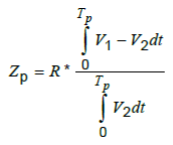
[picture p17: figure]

CONFIDENTIAL
All information contained in this document is confidential and is the sole property of Med-Ally Inc. Any reproduction in part or whole without the
Qualification Test | Testing Details
| | ohm +/- 2 % resistor. ►The LEAD stimulation IMPEDANCE (Zp) shall be calculated, using the mean values of voltage and current, by applying the formula: NOTE See Figure 120 and Figure 121 for definitions of V1 and V2.
| Report | ► Generate Report
Qualification Test | Testing Details
| Purpose | ►Ensure Leads meet requirements, standards, and performance characteristics for the 2 years.
| Standards | ►ISO 14708-1:19-1
| Acceptance Criteria | ►Meets functional specifications at appropriate time points. ►There is no visible corrosion or delamination apparent that would lead to connection of two conducting surfaces. ►No unacceptable risks become evident as the device ages.
| Equipment | ►Oven ►RH Meter ►Timer ►Temperature Probe and Meter
| Lead Samples | ►20 cm leads will be utilized. ►Qty 9 VNS leads as representative samples will be used of a cuff lead sample with the DC charge test.
| Test Set Up | ►Consider the composition, morphology, thermal transitions, additives or other chemical properties present in materials. ► Assumptions: - Conditioned in 0.9% sodium chlorine bath heated to 55 degrees C per accelerated aging standards outlined in ISO 11607-1:2006 and ASTM F1980-07(2011)

Lead accelerated
aging test

### Hornet Lead – Test Plan

### Page 12 of 12

CONFIDENTIAL
All information contained in this document is confidential and is the sole property of Med-Ally Inc. Any reproduction in part or whole without the
Qualification Test | Testing Details
- Accelerating Aging Temperature 55 degrees C
- Nominal temperature 37 degrees C
- Q10 value of 2.0
- With the above calculations the testing timepoints:
| • 3 months = 26 days • 12 months = 52 days • 24 months = 105 days • 36 months = 314 days • 48 months = 419 days • 60 months = 524 days
- Team may decide to increase temperature depending on timepoint
| calculation will change accordingly ►Place the Aging Parts in prepared saline bath and place in designated oven and record start time and date. Record temperature measurement calibration information. ►Age Samples at Accelerated Aging Temperature, and in parallel, age samples at room temperature. ►At the end of each Aging Test Time Interval, visually inspect device and verify performance requirements of the device. Place device back in chamber after testing to continue the conditioning.

Report

| ►Generate Report, including aging conditions (test temperature, humidity, cycle, ambient temperature, time frame, sample sizes, time intervals of sampling, and specific tests at each time interval). Record all instruments used and calibration information. Document test standard references and

methods of evaluation.

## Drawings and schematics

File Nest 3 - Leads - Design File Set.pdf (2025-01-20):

# DRAFT

ITEM NO. | PART NUMBER | DESCRIPTION | QTY. | | REVISIONS

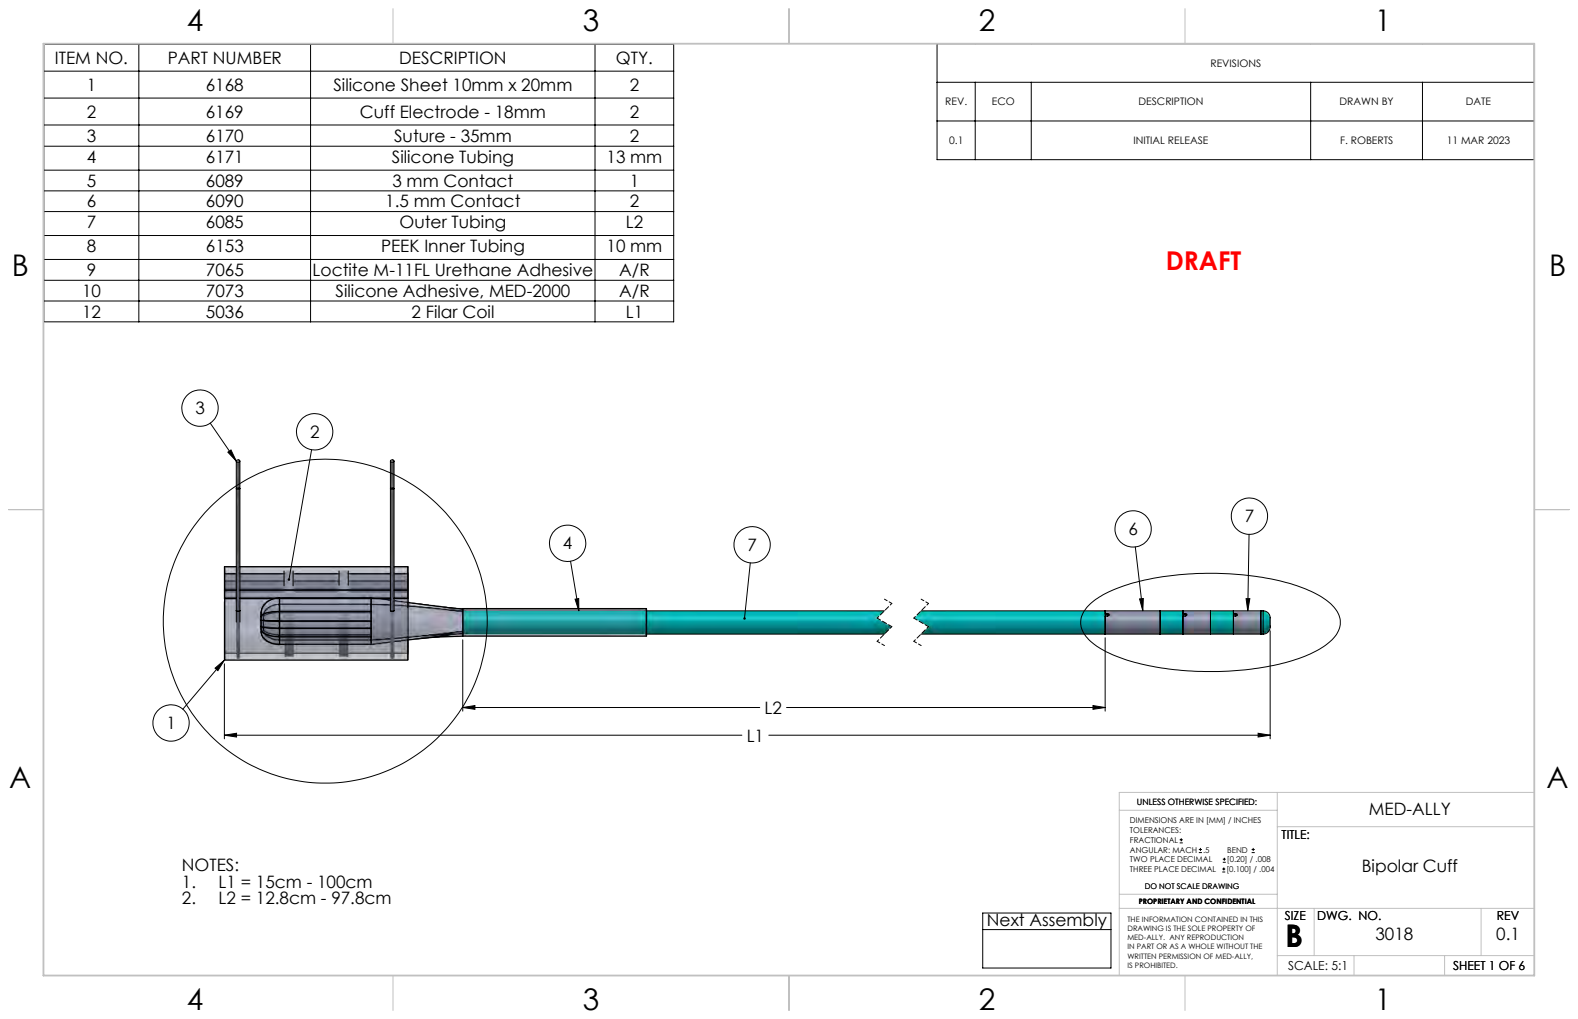
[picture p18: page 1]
NOTES: 1. L1 = 15cm - 100cm 2. L2 = 12.8cm - 97.8cm; TITLE:; ANGULAR: MACH .5; BEND; TWO PLACE DECIMAL; MED-ALLY; Next Assembly; Bipolar Cuff

1 | 6168 | Silicone Sheet 10mm x 20mm | 2
2 | 6169 | Cuff Electrode - 18mm | 2
3 | 6170 | Suture - 35mm | 2
4 | 6171 | Silicone Tubing | 13 mm
5 | 6089 | 3 mm Contact | 1
6 | 6090 | 1.5 mm Contact | 2
7 | 6085 | Outer Tubing | L2
8 | 6153 | PEEK Inner Tubing | 10 mm
9 | 7065 | Loctite M-11FL Urethane Adhesive | A/R
10 | 7073 | Silicone Adhesive, MED-2000 | A/R
12 | 5036 | 2 Filar Coil | L1

REV. | ECO | DESCRIPTION | DRAWN BY | DATE

0.1 | | INITIAL RELEASE | F. ROBERTS | 11 MAR 2023

UNLESS OTHERWISE SPECIFIED:
DIMENSIONS ARE IN [MM] / INCHES
TOLERANCES:
FRACTIONAL
THREE PLACE DECIMAL [0.100] / .004
DO NOT SCALE DRAWING
PROPRIETARY AND CONFIDENTIAL

THE INFORMATION CONTAINED IN THIS DRAWING IS THE SOLE PROPERTY OF MED-ALLY. ANY REPRODUCTION IN PART OR AS A WHOLE WITHOUT THE WRITTEN PERMISSION OF MED-ALLY, IS PROHIBITED. | SIZE SIZE B B | DWG. NO. DWG. NO. 3018 | REV REV 0.1

SCALE: 5:1 | | SHEET 1 OF 6

# DRAFT

B | B

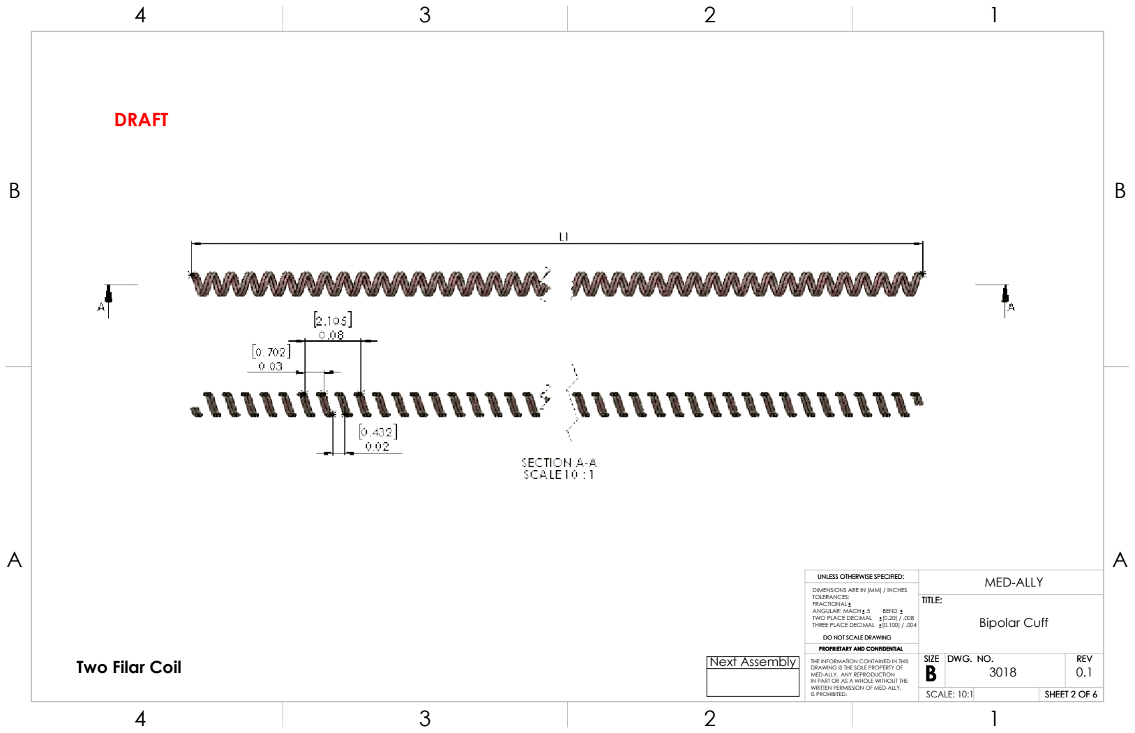
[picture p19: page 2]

# Two Filar Coil

DO NOT SCALE DRAWING

UNLESS OTHERWISE SPECIFIED:

THE INFORMATION CONTAINED IN THIS DRAWING IS THE SOLE PROPERTY OF | SIZE SIZE B B | DWG. NO. DWG. NO. 3018 | REV REV 0.1

## SCALE: 10:1

## TITLE:

PROPRIETARY AND CONFIDENTIAL

A | A

DO NOT SCALE DRAWING

UNLESS OTHERWISE SPECIFIED:

## TITLE:

DIMENSIONS ARE IN [MM] / INCHES TOLERANCES:
FRACTIONAL
ANGULAR: MACH .5 | BEND
TWO PLACE DECIMAL | [0.20] / .008
THREE PLACE DECIMAL [0.100] / .004

PROPRIETARY AND CONFIDENTIAL

# MED-ALLY

# Next Assembly

# Bipolar Cuff

# DRAFT

B | B

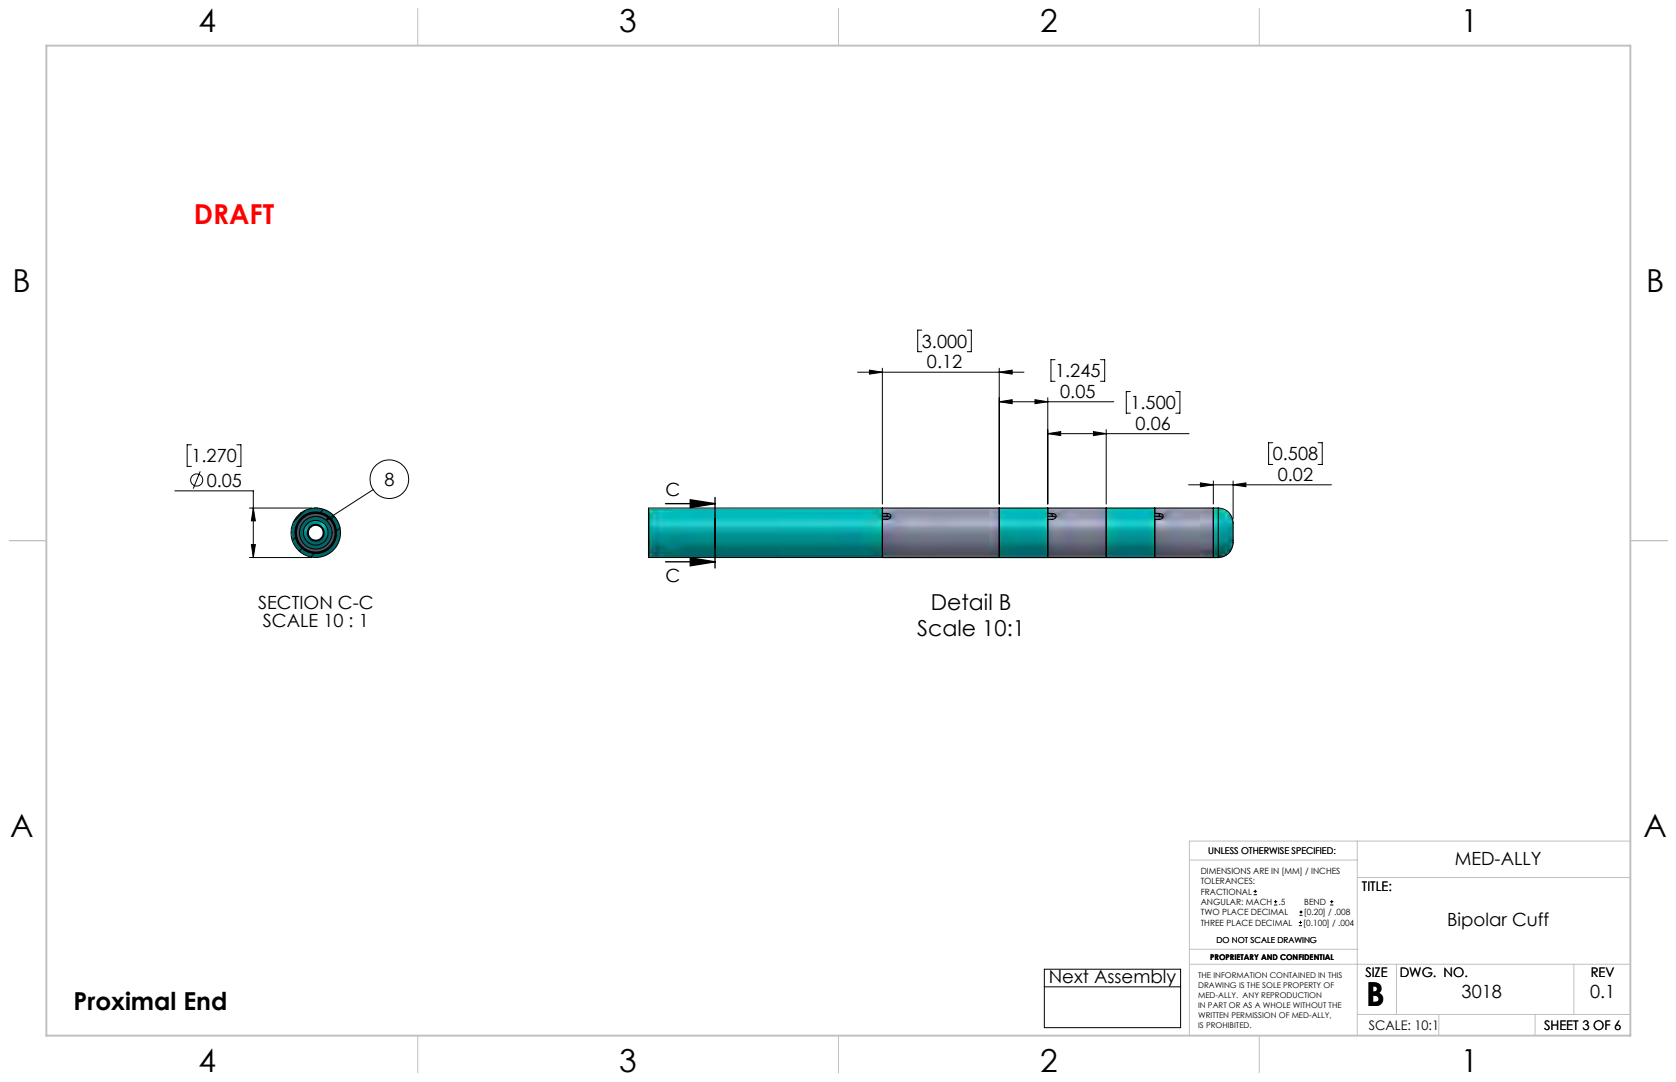
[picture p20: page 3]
SECTION C-C SCALE 10 : 1; Detail B Scale 10:1; Proximal End; TITLE:; ANGULAR: MACH .5; BEND; TWO PLACE DECIMAL; MED-ALLY; Next Assembly; Bipolar Cuff

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

SCALE: 10:1

# DRAFT

B | B

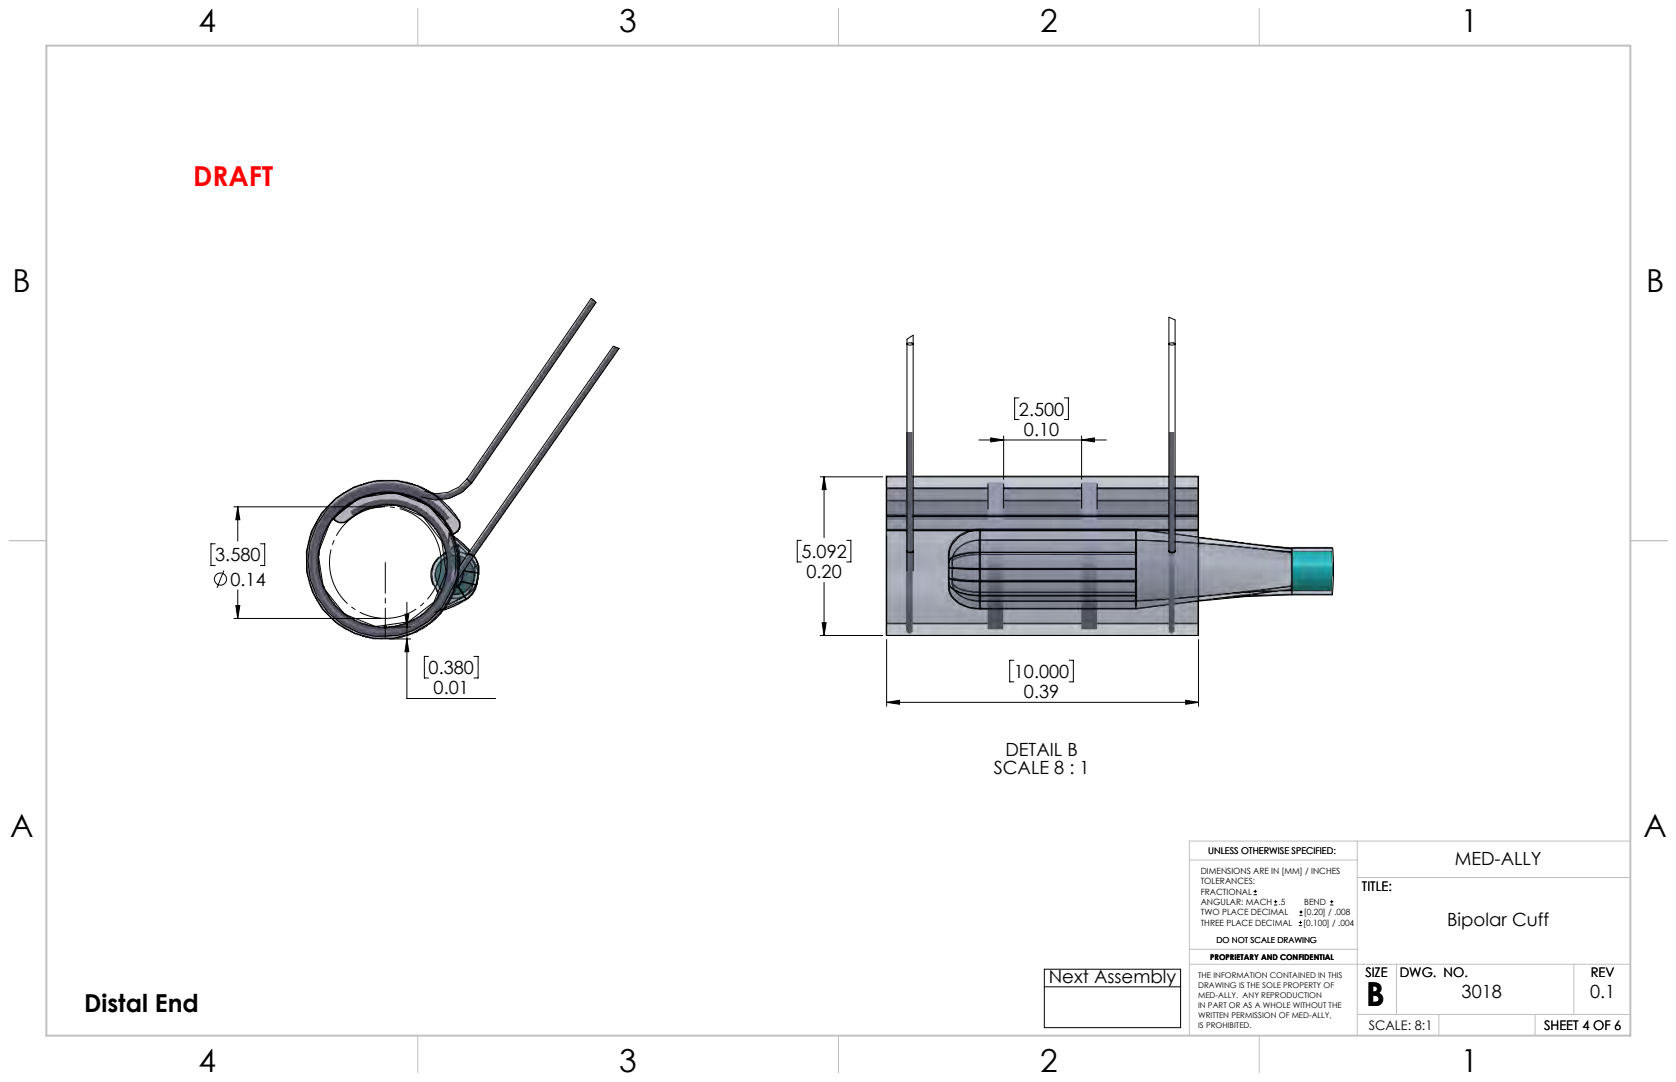
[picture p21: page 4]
DETAIL B SCALE 8 : 1; Distal End; TITLE:; ANGULAR: MACH .5; BEND; TWO PLACE DECIMAL; MED-ALLY; Next Assembly; Bipolar Cuff

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

SCALE: 8:1

20.000
0.79

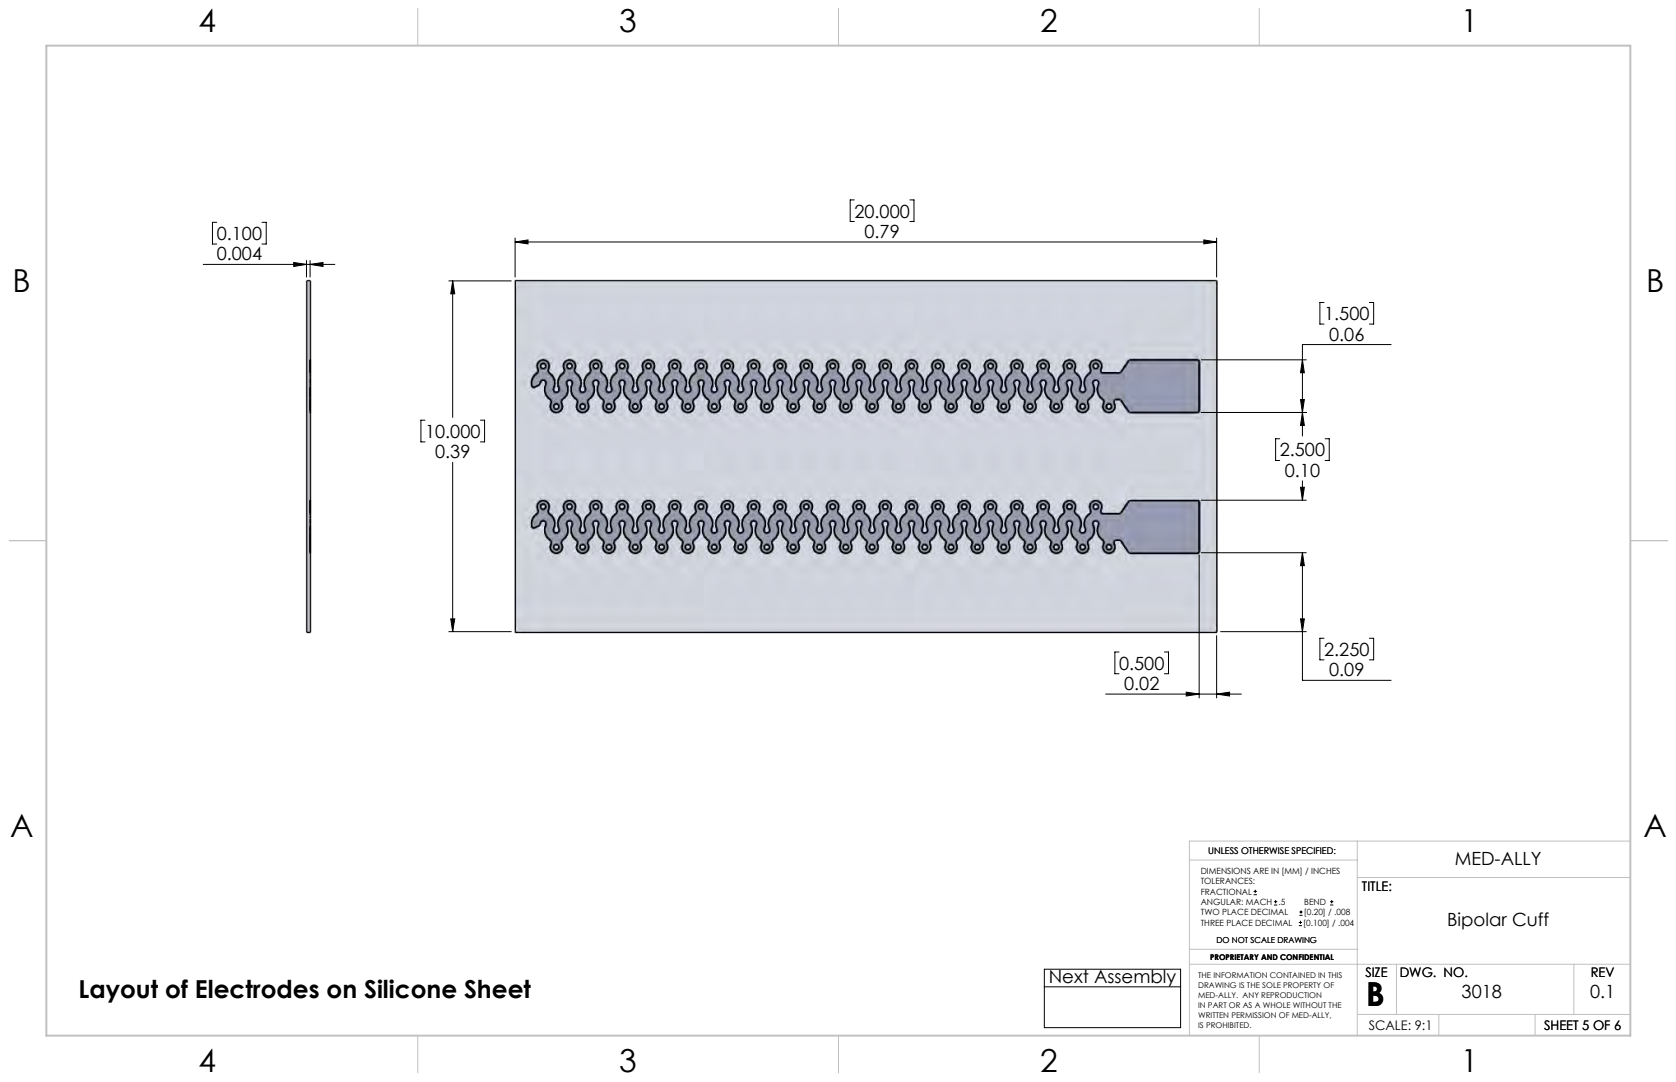
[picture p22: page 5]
TITLE:; ANGULAR: MACH .5; BEND; TWO PLACE DECIMAL; MED-ALLY; Next Assembly; Bipolar Cuff

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

Layout of Electrodes on Silicone Sheet

SCALE: 9:1

# DRAFT

B | B

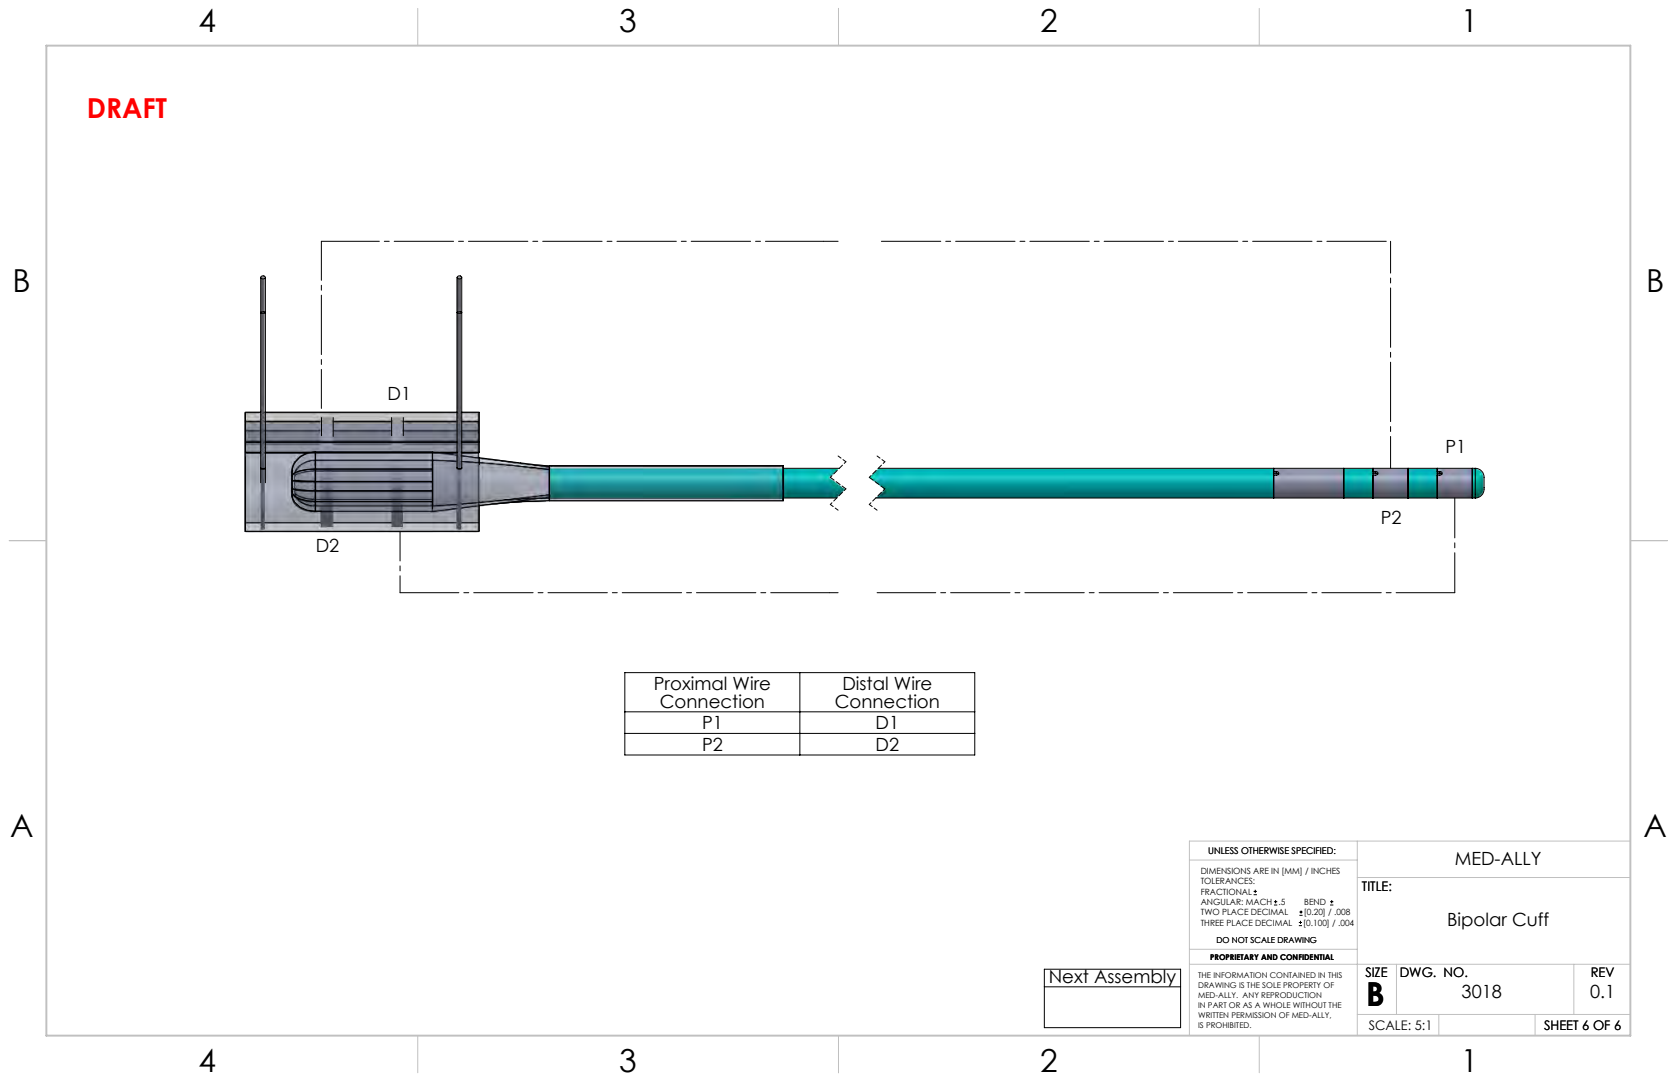
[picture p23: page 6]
TITLE:; ANGULAR: MACH .5; BEND; TWO PLACE DECIMAL; MED-ALLY; Next Assembly; Bipolar Cuff

Proximal Wire Connection | Distal Wire Connection
P1 | D1
P2 | D2

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

SCALE: 5:1

L3 | L2

L1

REV. | ECO | DESCRIPTION | DRAWN BY | DATE

0.1 | | INITIAL RELEASE | F. ROBERTS | 15 MAR 2023

ITEM NO. | PART NUMBER | DESCRIPTION | QTY.
1 | 6089 | Proximal Contact - 3mm | 1
2 | 6085 | Outer Tubing | L2, L3
3 | 6090 | Proximal Contact - 1.5 mm | 2
5 | 6175 | Distal Suture Tip | 1
6 | 6176 | Suture Sleeve | 1
7 | 6081-3 | Electrode, 3mm | 2
8 | 6153 | PEEK Single Lumen Tube | 9mm

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

THE INFORMATION CONTAINED IN THIS DRAWING IS THE SOLE PROPERTY OF | SIZE SIZE B B | DWG. NO. DWG. NO. 3020 | REV REV 0.1

SCALE: 7:1

B | B
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

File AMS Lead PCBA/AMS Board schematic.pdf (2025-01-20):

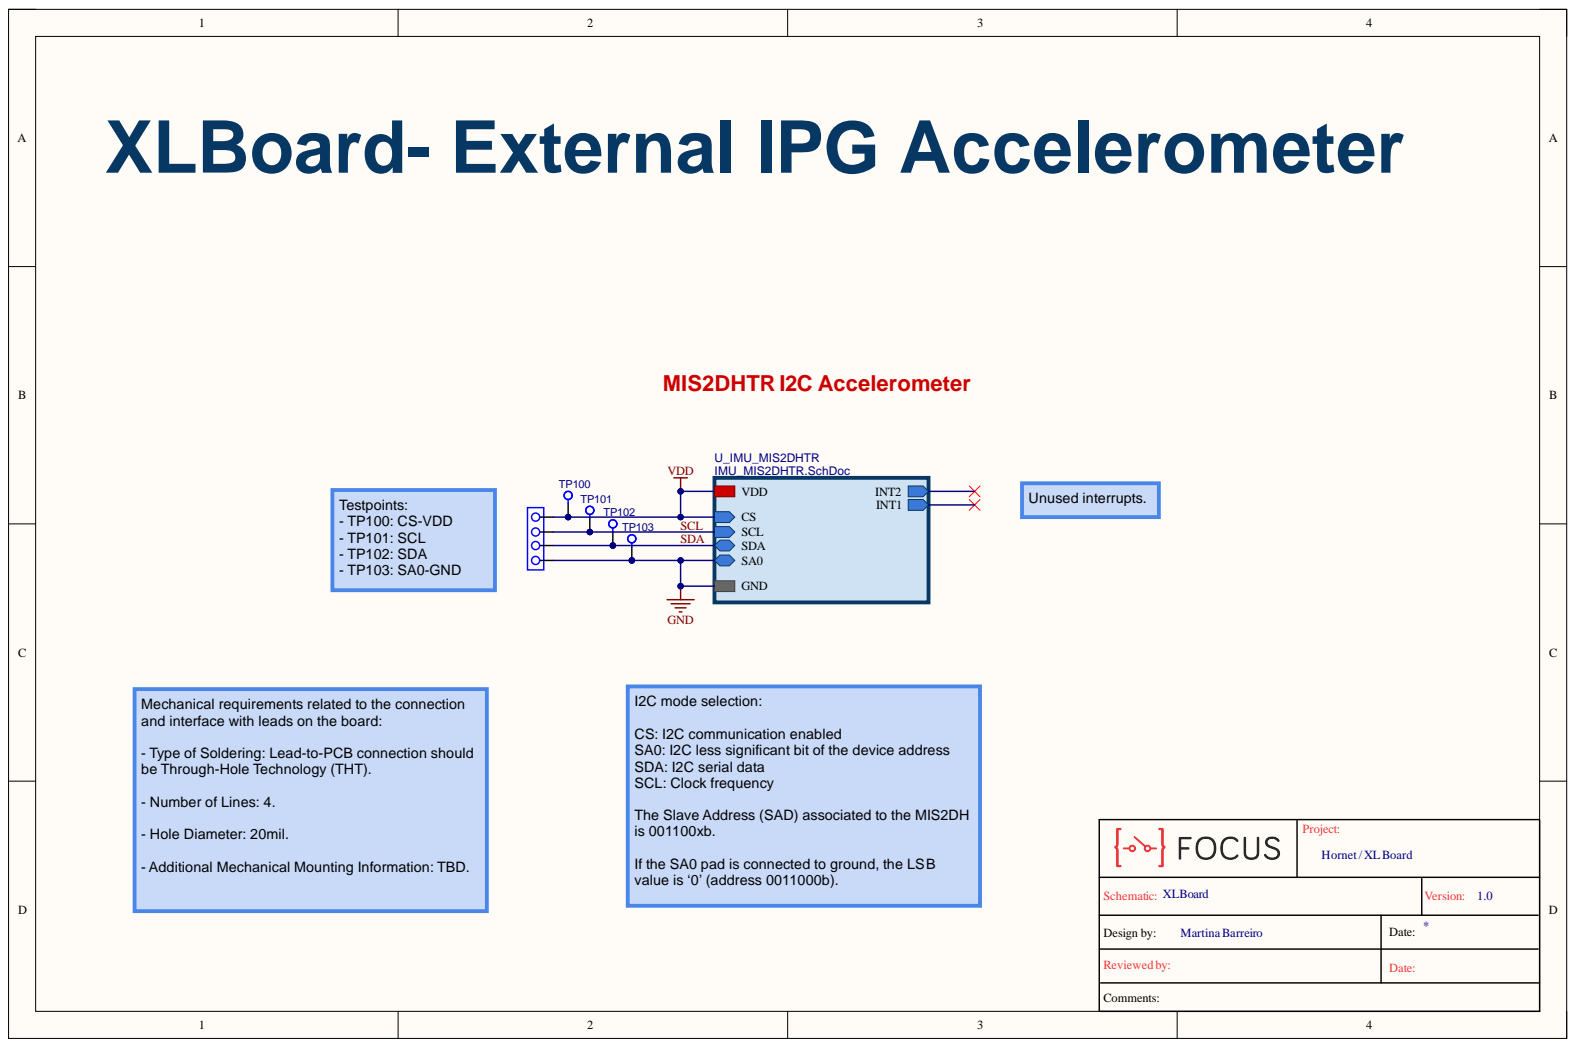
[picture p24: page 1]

XLBoard- External IPG Accelerometer

SCL TP103

SDA

Mechanical requirements related to the connection
and interface with leads on the board:

I2C mode selection: CS: I2C communication enabled

- Type of Soldering: Lead-to-PCB connection should
be Through-Hole Technology (THT).

SA0: I2C less significant bit of the device address
SDA: I2C serial data
SCL: Clock frequency

The Slave Address (SAD) associated to the MIS2DH is 001100xb.

Project: Hornet / XL Board

- Additional Mechanical Mounting Information: TBD.

If the SA0 pad is connected to ground, the LSB
value is

Schematic: XLBoard | Version: 1.0

Design by: Martina Barreiro | * Date:

Date:

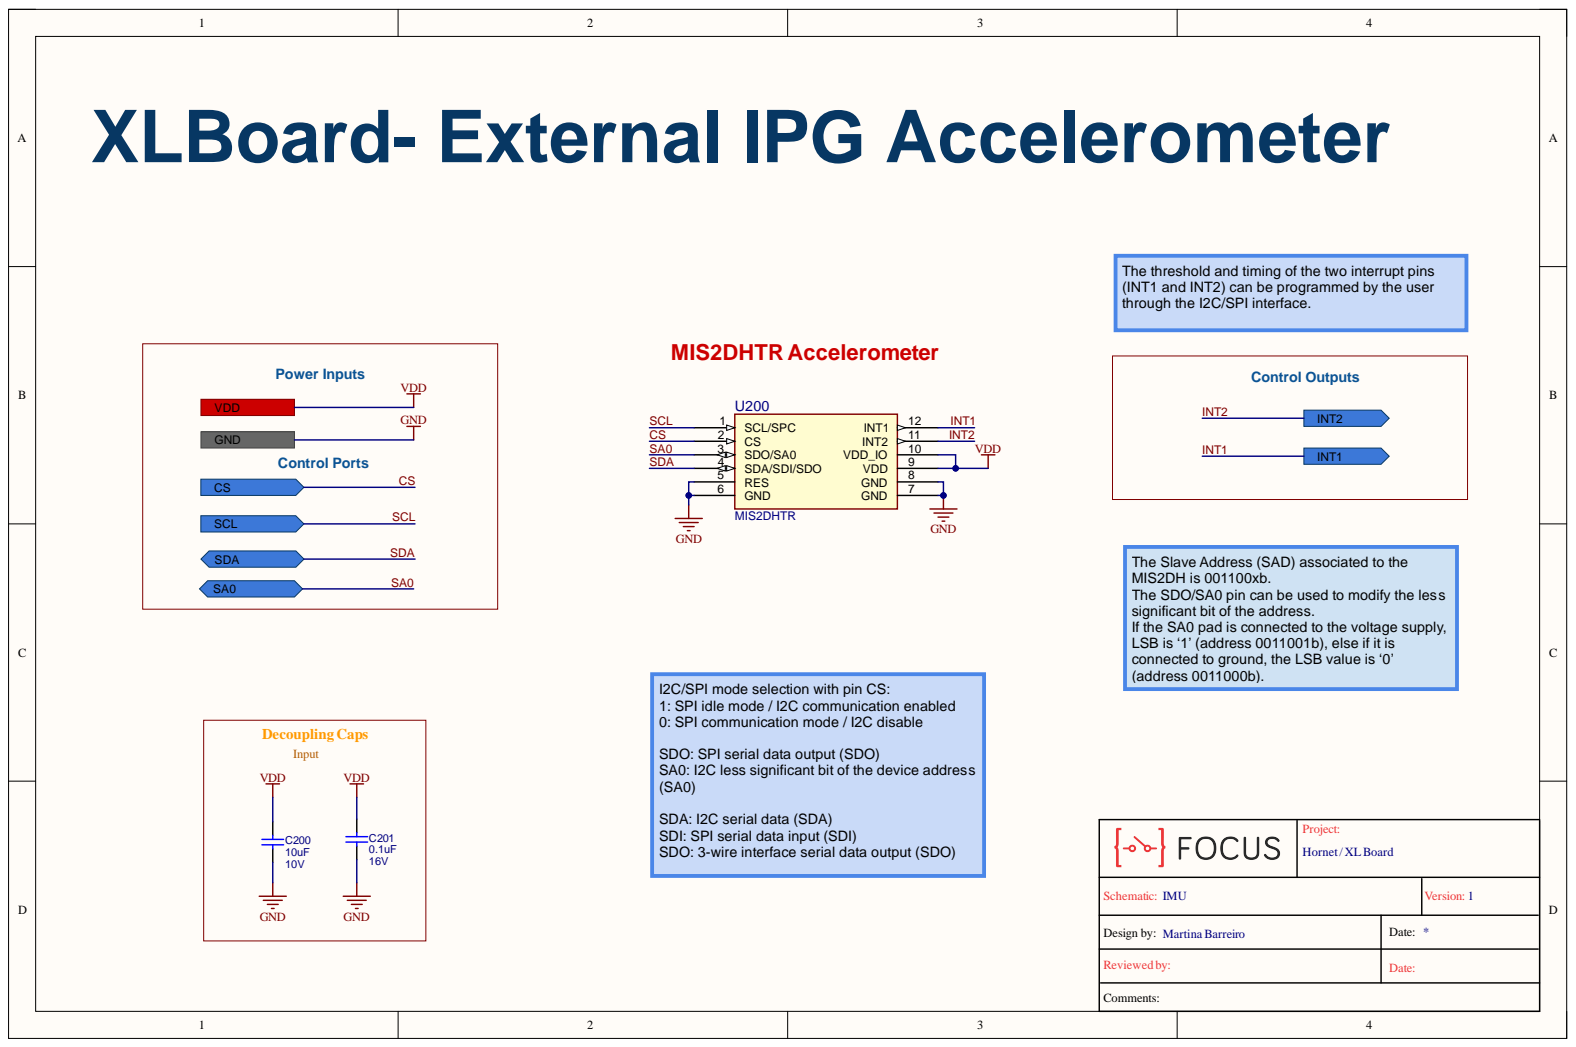
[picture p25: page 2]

P roje c t : Boa r d

S chema ti c : IMU | Ve rsio n : 1

Design by: Reviewed by Ma rtina B a r r e ir o | Da te : *

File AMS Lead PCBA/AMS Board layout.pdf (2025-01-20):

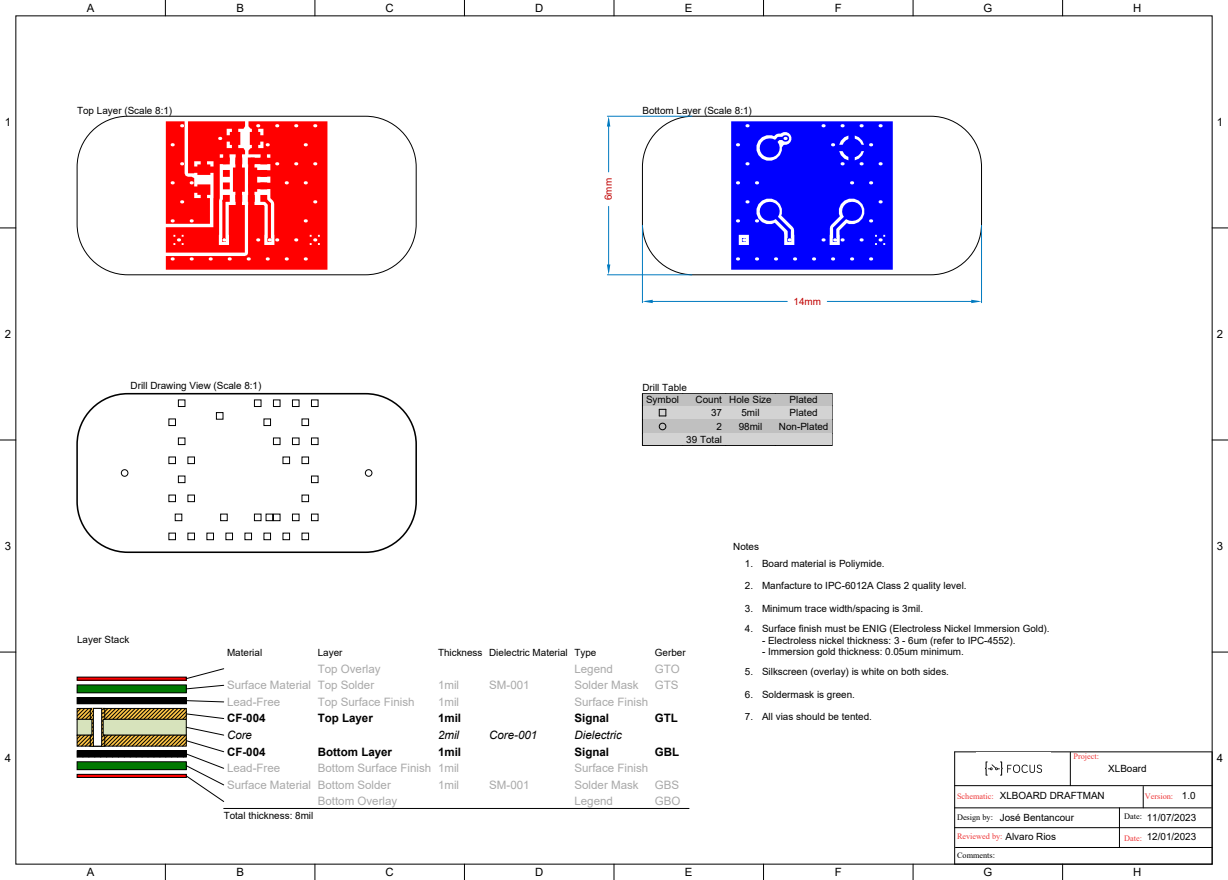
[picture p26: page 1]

Drill Drawing View (Scale 8:1)

Symbol | Count | Hole Size | Plated

37 | 5mil | Plated
2 | 98mil | Non-Plated
39 Total

Notes
1. Board material is Poliymide.

2. Manfacture to IPC-6012A Class 2 quality level.

3. Minimum trace width/spacing is 3mil.
Surface finish must be ENIG (Electroless Nickel Immersion Gold).
- Electroless nickel thickness: 3 - 6um (refer to IPC-4552).
- Immersion gold thickness: 0.05um minimum.
5. Silkscreen (overlay) is white on both sides.

7. All vias should be tented.

Project: XLBoard

XLBOARD DRAFTMAN Schematic: | 1.0 Version:

Design by: José Bentancour | Date: 11/07/2023

Reviewed by: Alvaro Rios | Date: 12/01/2023
